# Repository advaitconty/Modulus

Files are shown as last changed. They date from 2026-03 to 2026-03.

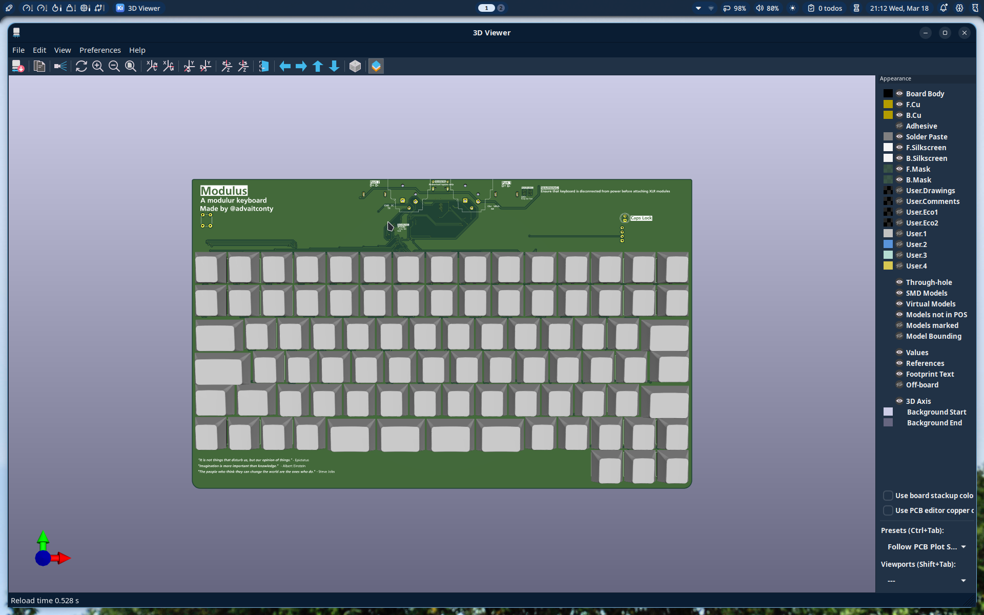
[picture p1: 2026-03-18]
Readme Images/Screenshot from 2026-03-18 21-12-29.png

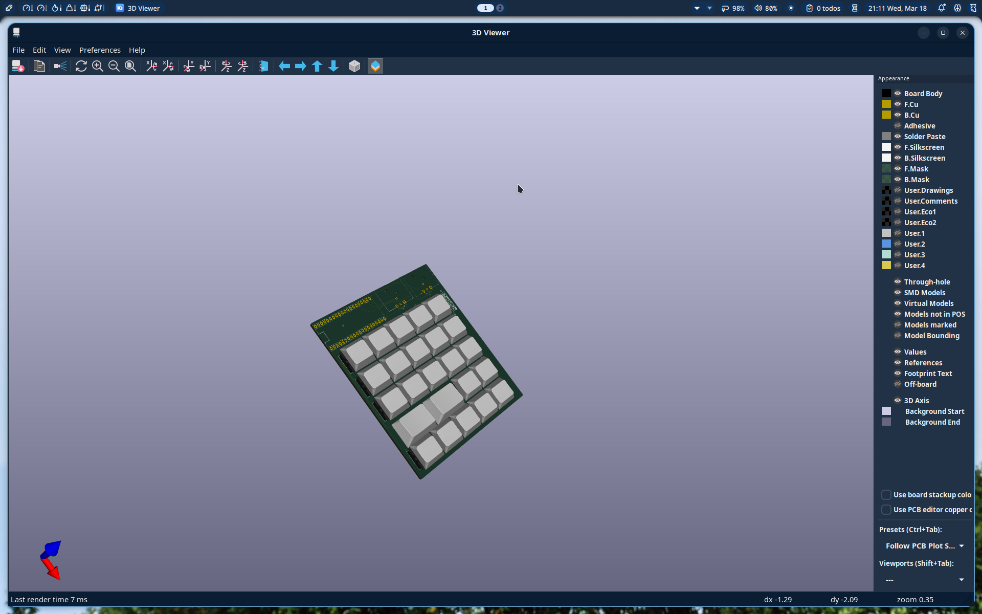
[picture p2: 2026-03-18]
Readme Images/Screenshot from 2026-03-18 21-11-40.png

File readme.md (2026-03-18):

# Modulus

A keyboard, built with the idea of expansion in the future, through SPI.

Things I will do later in the future (with other Hack Club events, or with my own money):
- Numpad over SPI
- Macropad over SPI

Just use it like a keyboard! However, any SPI accessories should be connected while the keyboard is powered down. This is mainly a limitation of SPI, as it is not hot-plug compatible.
The USB ports are USB 2.0 only, so it's better to be used for stuff like USB sound cards and mice.
I don't actually know how much lag will the ports create, because they're bottom mounted, in direct contact with foam, and is air cooled. So it may overheat (tried to add thermal dissiptation vias but effectiveness not tested)

Quirks:
- Case has holes at the bottom for cooling (yes I'm serious)

## Images

- model + board

- board only

(https://imgcdn.dev/i/YvtLNg)
(https://imgcdn.dev/i/YvtbGv)
(https://imgcdn.dev/i/YvteeN)
(https://imgcdn.dev/i/YvtqMq)
(https://imgcdn.dev/i/Yv8obV)
(https://imgcdn.dev/i/Yv8JGh)
(https://imgcdn.dev/i/YvJDMK)
(https://imgcdn.dev/i/YvJYlo)

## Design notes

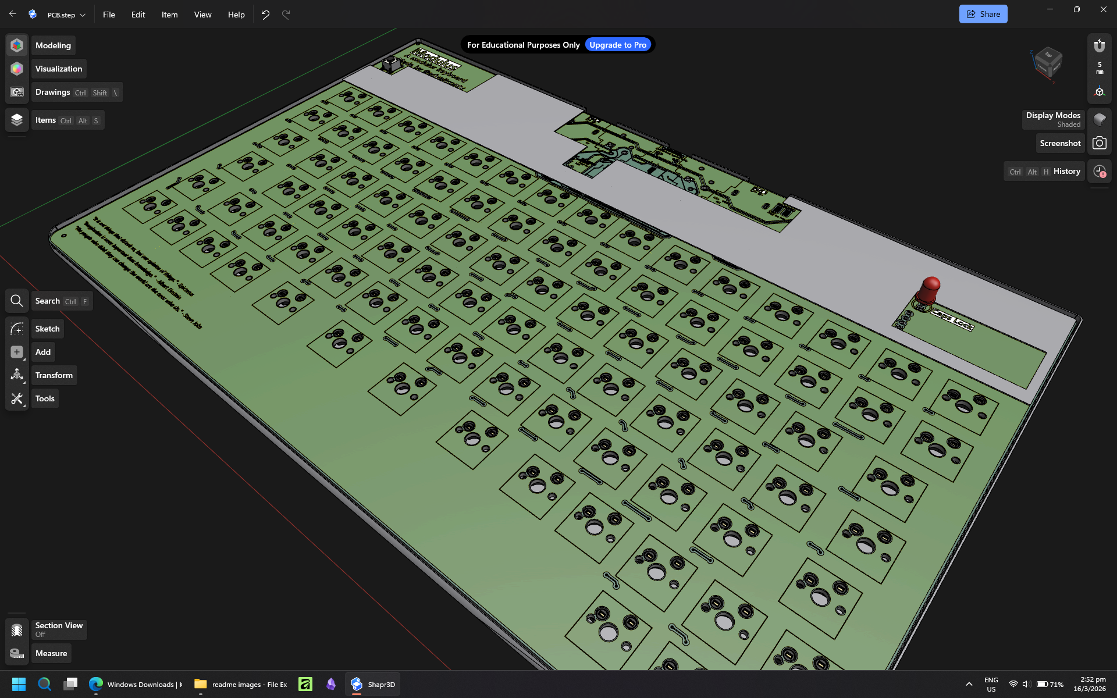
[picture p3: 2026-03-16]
Readme Images/Screenshot 2026-03-16 145249.png

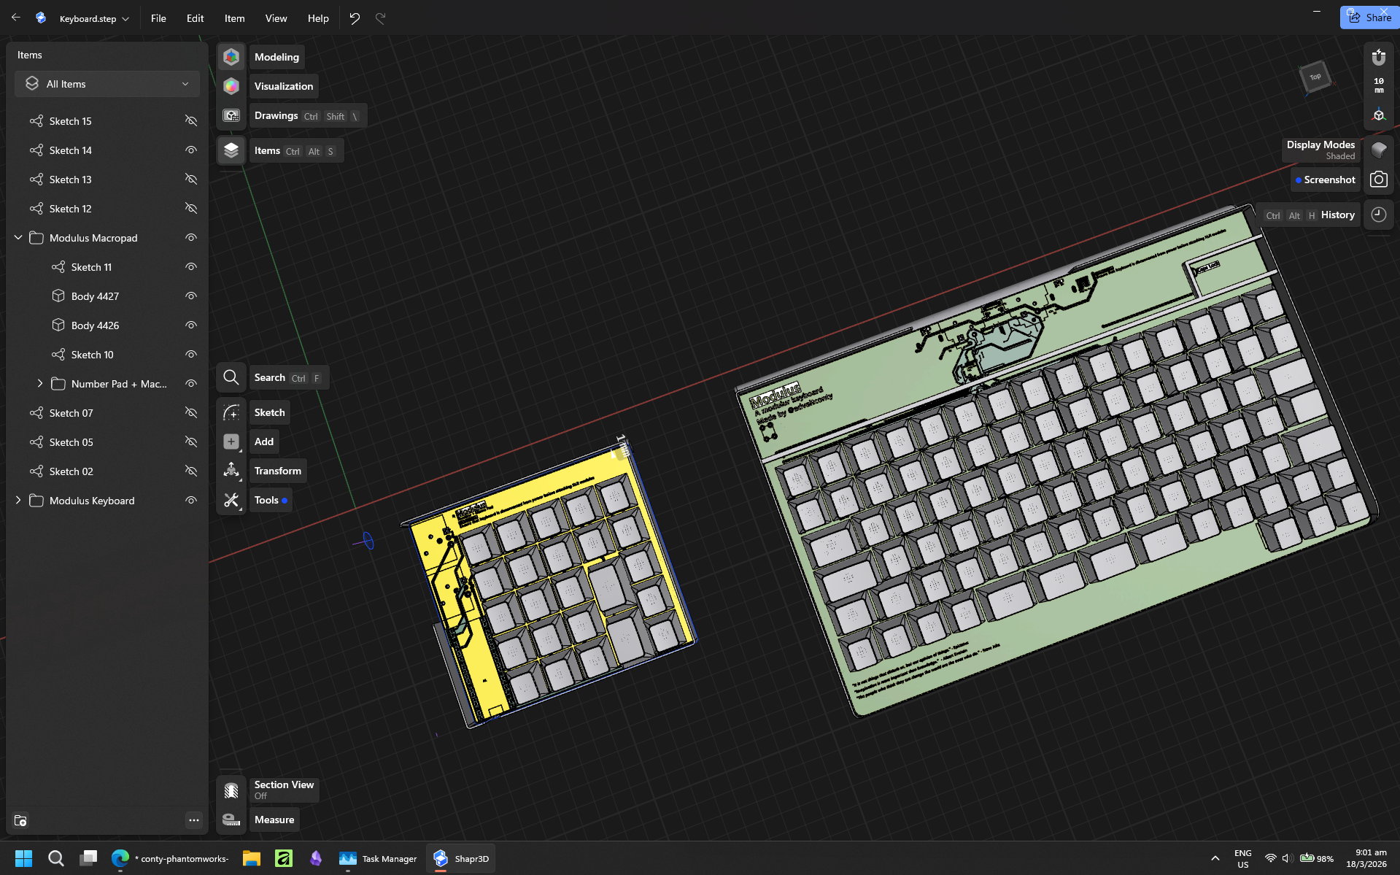
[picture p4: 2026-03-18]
Readme Images/With Macropad model.png

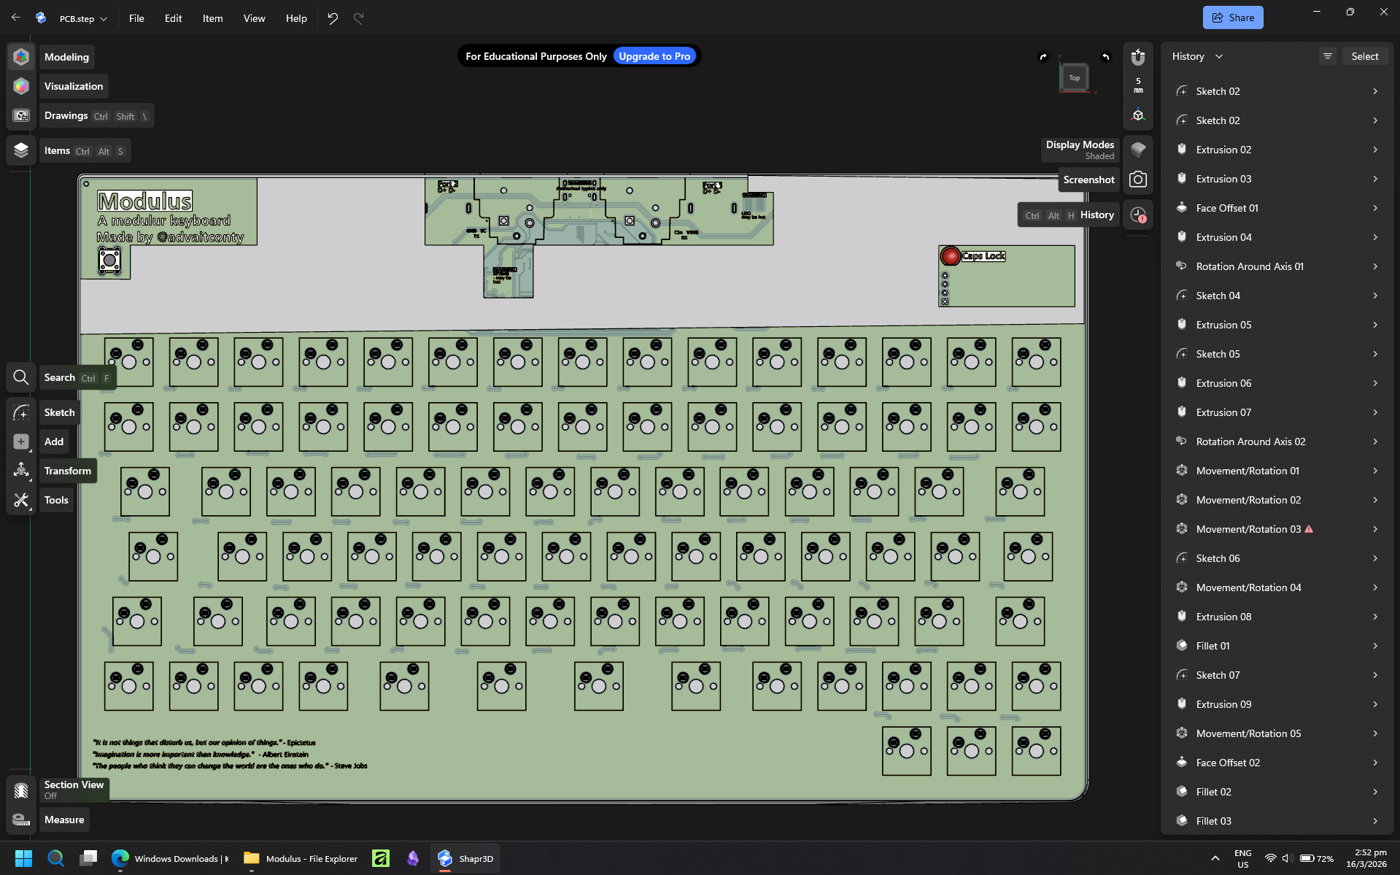
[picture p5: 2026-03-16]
Readme Images/Screenshot 2026-03-16 145220.png

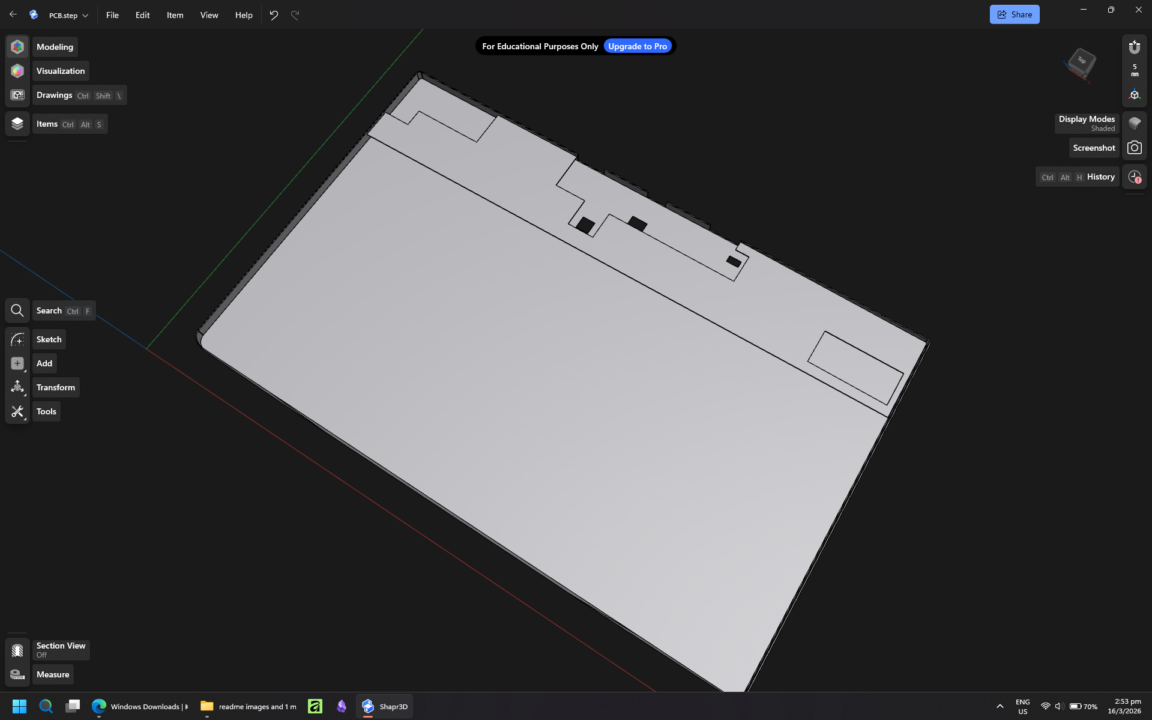
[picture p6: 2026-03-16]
Readme Images/Screenshot 2026-03-16 145345.png

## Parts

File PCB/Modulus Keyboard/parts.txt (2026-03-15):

I/O
Type C Receptable - https://jlcpcb.com/partdetail/Korean_HropartsElec-TYPE_C_31_M12/C165948
2x XLR - NC3FAAH - https://jlcpcb.com/partdetail/HOOYA-XLR_328P1/C309328
2x USB - https://jlcpcb.com/partdetail/7254738-USB1046_GF_0190_L_BA/C6307429

Chips
GL850G-HHY20 - https://jlcpcb.com/partdetail/GenesysLogic-GL850GHHY22/C136617
RP2040 - https://jlcpcb.com/partdetail/RaspberryPi-RP2040/C2040
Crystal - https://jlcpcb.com/partdetail/YXC_CrystalOscillators-X322512MSB4SI/C9002

Resistors
220ohm (0805) - https://jlcpcb.com/partdetail/18245-0805W8F2200T5E/C17557

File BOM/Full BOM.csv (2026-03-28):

Model | Item | Purpose | Vendor | Link | Qty | Unit Price | Total Price | Remarks
Neutrik NC3FAAH | XLR Connector (Female) | SPI over XLR connections on keyboard | LCSC | https://www.lcsc.com/product-detail/C368521.html | 2 | $1.59 | $3.18
Neutrik NC3MAH | XLR Connector (Male) | SPI over XLR connections on macropad | LCSC | https://www.lcsc.com/product-detail/C5154126.html | 2 | $1.98 | $3.96
BZCN TSD001A05518A | Button 6mmX6mm | Reset button | LCSC | https://www.lcsc.com/product-detail/C2889004.html | 50 | $0.01 | $0.50 | Purchase 50 due to minimum purchase quantity
UGREEN 60121 | USB-A to USB-C Cable (1m) | Keyboard connection | LCSC | https://www.lcsc.com/product-detail/C5189133.html | 1 | $2.54 | $2.54
Han Electricity CPG151101S11-16 | Hotswap Keyswitch | For keyboard | LCSC | https://www.lcsc.com/product-detail/C41430893.html | 120 | $0.03 | $4.12
Global Direct Standard Line | Shipping | Shipping | LCSC | - | 1 | $5.50 | $5.50
Keyboard | PCB | PCB | JLC | - | 5 | $28.00 | $28.00
Keyboard | PCB Assembly | Setup Fee | JLC | - | 1 | $8.12 | $8.12
Keyboard | PCB Assembly | Stencil | JLC | - | 1 | $1.52 | $1.52
Keyboard | PCB Assembly | Components | JLC | - | 1 | $14.94 | $14.94
Keyboard | PCB Assembly | Extended Components Fee | JLC | - | 1 | $18.24 | $18.24
Keyboard | PCB Assembly | SMT Assembly | JLC | - | 1 | $1.39 | $1.39
Keyboard | PCB Assembly | Nitrogen Reflow Soldering | JLC | - | 1 | $0.85 | $0.85
Macropad | PCB | PCB | JLC | - | 5 | $11.00 | $11.00
Macropad | PCB Assembly | Setup Fee | JLC | - | 1 | $8.12 | $8.12
Macropad | PCB Assembly | Stencil | JLC | - | 1 | $1.52 | $1.52
Macropad | PCB Assembly | Components | JLC | - | 1 | $0.55 | $0.55
Macropad | PCB Assembly | SMT Assembly | JLC | - | 1 | $0.16 | $0.16
Macropad | PCB Assembly | Nitrogen Reflow Soldering | JLC | - | 1 | $0.85 | $0.85
Shipping | Macropad + Keyboard Shipping | UPS Worldwide Saver | JLC | - | 1 | $19.71 | $19.71
KBDiy 147/Keys Modern-Dolch Keycaps | Keycaps for Keyboard | Keycaps | AliExpress | https://www.aliexpress.com/item/1005010169995953.html?mp=1 | 1 | $19.70 | $19.70
Samzhe XLR Cable | XLR Cables | For connecting macropad and keyboard | AliExpress | https://www.aliexpress.com/item/1005005725048225.html?mp=1 | 2 | $6.43 | $12.86
Outemu Silent Lemon V3s 110 switch pack | Keyswitch | Very nice keyswitch | AliExpress | https://www.aliexpress.com/item/1005005609580877.html?mp=1 | 1 | $21.03 | $21.03
128x32 OLED | Screen | Indicator on Keyboard | AliExpress | https://www.aliexpress.com/item/1005005301005280.html?mp=1 | 1 | $2.79 | $2.79 | I burnt the last one i soldered so i shall be smart and get one pre soldered-
Soldering Iron Tip | Chisel | For my tipless pinecil | AliExpress | https://www.aliexpress.com/item/1005006125240838.html?curPageLogUid=HrnIASZUeSxM | 1 | $5.03 | $5.03 | I was told this was allowed (https://hackclub.slack.com/archives/C09CMJV6V6K/p1774712666820039?thread_ts=1774710807.451839&cid=C09CMJV6V6K)
 |  |  |  |  |  | Total: | $196.18

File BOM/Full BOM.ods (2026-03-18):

Model | Item | Purpose | Vendor | Link | Qty | Unit Price | Total Price | Remarks
Neutrik NC3FAAH | XLR Connector (Female) | SPI over XLR connections on keyboard | LCSC | https://www.lcsc.com/product-detail/C368521.html | 2 | $1.59 | $3.17
Neutrik NC3MAH | XLR Connector (Male) | SPI over XLR connections on macropad | LCSC | https://www.lcsc.com/product-detail/C5154126.html | 2 | $1.98 | $3.96
BZCN TSD001A05518A | Button 6mmX6mm | Reset button | LCSC | https://www.lcsc.com/product-detail/C2889004.html | 50 | $0.01 | $0.53 | Purchase 50 due to minimum purchase quantity
UGREEN 60121 | USB-A to USB-C Cable (1m) | Keyboard connection | LCSC | https://www.lcsc.com/product-detail/C5189133.html | 1 | $2.54 | $2.54
Global Direct Standard Line | Shipping | Shipping | LCSC | - | 1 | $5.41 | $5.41
Modulus | Macropad | PCB | JLCPCB | - | 5 | - | $11.00
Modulus | Macropad PCBA | Assembly | JLCPCB | - | 2 | - | $16.39 | Refer to BOM for macropad (in same folder) for parts used
Modulus | Keyboard | PCB | JLCPCB | - | 5 | - | $25.70
Modulus | Keyboard PCBA | Assembly | JLCPCB | - | 2 | - | $55.43 | Refer to BOM for keyboard (in same folder) for parts used
UPS Worldwide Express Saver | Shipping | PCB shipping | JLCPCB | - | 1 | $18.67 | $18.67
KBDiy 147/Keys Modern-Dolch Keycaps | Keycaps for Keyboard | Keycaps | AliExpress |  | 1 | S$23.10 | S$23.10
Samzhe XLR Cable | XLR Cables | For connecting macropad and keyboard | AliExpress |  | 2 | S$7.09 | S$14.18
Outemu Silent Lemon V3s 110 switch pack | Keyswitch | Very nice keyswitch | AliExpress |  | 1 | S$29.17 | S$29.17
128x32 OLED | Screen | Indicator on Keyboard | AliExpress |  | 1 | S$3.47 | S$3.47 | I burnt the last one i soldered so i shall be smart and get one pre soldered-
 |  |  |  |  |  | TOTAL: | $197.40 | (usd)

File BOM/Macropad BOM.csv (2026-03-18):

Comment | Designator | Footprint | JLCPCB Part #
~ | S18,S1,S10,S11,S12,S13,S14,S15,S16,S17,S2,S20,S21,S22,S23,S24,S3,S4,S5,S6,S7,S8,S9,S18,S1,S10,S11,S12,S13,S14,S15,S16,S17,S2,S20,S21,S22,S23,S24,S3,S4,S5,S6,S7,S8,S9 | SW_Hotswap_Kailh_MX_1.00u | C41430893
Diode | D25,D1,D10,D11,D12,D13,D14,D15,D16,D17,D18,D19,D2,D20,D21,D22,D23,D24,D3,D4,D5,D6,D7,D8,D9,D25,D1,D10,D11,D12,D13,D14,D15,D16,D17,D18,D19,D2,D20,D21,D22,D23,D24,D3,D4,D5,D6,D7,D8,D9 | D_SMA | C81598

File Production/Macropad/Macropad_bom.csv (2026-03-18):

Designator | Footprint | Quantity | Value | LCSC Part #
A1 | raspberry_pi_pico_THT | 1 | Raspberry_Pi_Pico_THT
D1, D10, D11, D12, D13, D14, D15, D16, D17, D18, D19, D2, D20, D21, D22, D23, D24, D3, D4, D5, D6, D7, D8, D9 | D_SMA | 24 | Diode | C81598
D25 | D_SMA | 1 | D_Generic
J10, J9 | NEUTRIK_NC3MAH | 2 | NC3MAH
S1, S10, S11, S12, S13, S14, S15, S16, S17, S2, S20, S21, S22, S23, S24, S3, S4, S5, S6, S7, S8, S9 | SW_Hotswap_Kailh_MX_1.00u | 22 | ~ | C41430893
S18 | SW_Hotswap_Kailh_MX_1.50u_90deg | 1 | ~ | C41430893
S19 | SW_Hotswap_Kailh_MX_1.50u_90deg | 1 | ~

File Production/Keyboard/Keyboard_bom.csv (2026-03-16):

Designator | Footprint | Quantity | Value | LCSC Part #
-_1, 0)1, 1!1, 2@1, 3#1, 4$1, 5%1, 6^1, 7&1, 8*1, 9(1, =+1, BACKSPACE1, BACKSPACE2, COMMAND1, COMMAND2, CONTROL1, DEL1, DEL2, DOWN1, E1, ESC1, F1, F10, F11, F12, F2, F3, F4, F5, F6, F7, F8, F9, FN1, I1, LEFT1, O1, OPTION1, OPTION2, P1, PGDOWN1, PGUP1, Q1, RIGHT1, RKEY1, S46, S47, S48, S49, S50, S51, S52, S53, S54, S55, S56, S57, S61, S62, S63, S64, S65, S66, S67, S68, S69, S70, S71, T1, UKEY1, UP1, W1, YKEY11, [{1, ]}1, `~1 | SW_Hotswap_Kailh_MX_1.00u | 77 | Keyswitch | C41430893
-_D1, 0)D1, 1!D1, 2@D1, 3#D1, 4$D1, 5%D1, 6^D1, 7&D1, 8*D1, 9(D1, =+D1, BACKSPACED1, BACKSPACED2, D31, D32, D33, D34, D35, D36, D37, D38, D39, D40, D41, D42, D43, D44, D45, D46, D47, D48, D49, D50, D51, D52, D53, D54, D55, D56, D57, D58, D59, D60, D61, D62, D63, D64, D65, D66, D67, D68, D69, D70, D71, D72, D73, D74, D75, D76, D77, D78, D79, D80, D81, D82, D84, D85, D86, D87, D88, D89, DELD1, DELD2, ESCD1, F10D1, F11D1, F12D1, F1D1, F2D1, F3D1, F4D1, F5D1, F6D1, F7D1, F8D1, F9D1, `~D1 | D_SMA | 88 | Diode | C81598
C1, C10 | 1206 | 2 | 1uF | C1848
C11, C12, C17, C2, C3, C4, C5, C6, C7, C8, C9 | 1206 | 11 | 0.1uF | C24497
C13, C14 | 1206 | 2 | 10uF | C13585
C15, C16, C20, C21 | 0805 | 4 | 33pF | C107115
C22, C23, C24, C25, C26, C27 | 1206 | 6 | 100nF | C1848
D91 | LED_D5.0mm | 1 | LED
GL850G1 | 28SSOP | 1 | GL850G | C7501406
J1, J5 | NEUTRIK_NC3FAAH | 2 | XLR3 | C368521
J2 | USB_C_HRO_TYPE-C-31-M-12 | 1 | USB_C_Receptacle_USB2.0_16P | C165948
J3, J4 | GCT_USB1046-GF-0190-L-B-A_REVB4 | 2 | USB_A | C6307429
J6 | OLED_128x32 | 1 | OLED_128x32
R1 | 0805 | 1 | 680 | C17798
R11 | 0402 | 1 | 88.7K | C25922
R12, R15, R16, R17, R7 | 1206 | 5 | 10K | C17902
R13, R8, R9 | 0805 | 3 | 5.1K | C27834
R14, R5, R6 | 1206 | 3 | 1K | C4410
R3, R4 | 0805 | 2 | 27 | C17594
S45 | SW_Hotswap_Kailh_MX_1.75u | 1 | Keyswitch | C41430893
S58, S59, S60 | SW_Hotswap_Kailh_MX_1.25u | 3 | Keyswitch | C41430893
S72, SPACE1, SPACE2, SPACE3, SPACE4, TAB1, \|1 | SW_Hotswap_Kailh_MX_1.50u | 7 | Keyswitch | C41430893
SW1 | SW_PUSH_6mm | 1 | Push_Button
U1 | QFN-56-1EP_7x7mm_P0.4mm_EP3.2x3.2mm | 1 | RP2040 | C2040
U3 | SOIC-8_5.3x5.3mm_P1.27mm | 1 | W25Q128JVS | C97521
U4 | SOT-223-3_TabPin2 | 1 | NCP1117-3.3_SOT223 | C26537
Y1, Y2 | Crystal_SMD_3225-4Pin_3.2x2.5mm | 2 | 12MHz | C9002

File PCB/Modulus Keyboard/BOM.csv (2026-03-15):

Reference | Qty | Value | Footprint | MF | MP | Package | Total Price | JLCPCB Part # | Extended Parts | Purchasing Seperately
-_1,0)1,1!1,2@1,3#1,4$1,5%1,6^1,7&1,8*1,9(1,=+1,Backspace1,Backspace2,Command1,Command2,Control1,Del1,Del2,Down1,E1,Esc1,F1,F2,F3,F4,F5,F6,F7,F8,F9,F10,F11,F12,Fn1,I1,Left1,O1,Option1,Option2,P1,PgDown1,PgUp1,Q1,Right1,RKey1,S46,S47,S48,S49,S50,S51,S52,S53,S54,S55,S56,S57,S61,S62,S63,S64,S65,S66,S67,S68,S69,S70,S71,T1,UKey1,UP1,W1,YKey11,[{1,]}1,`~1 | 88 | Keyswitch | ScottoKeebs_Hotswap:Hotswap_MX_1.00u | HanElectricity | CPG151101S11-16 | SMD,14.5x5.9mm | 3.82 | C41430893 | TRUE | FALSE
-_D1,0)D1,1!D1,2@D1,3#D1,4$D1,5%D1,6^D1,7&D1,8*D1,9(D1,=+D1,BackspaceD1,BackspaceD2,D31,D32,D33,D34,D35,D36,D37,D38,D39,D40,D41,D42,D43,D44,D45,D46,D47,D48,D49,D50,D51,D52,D53,D54,D55,D56,D57,D58,D59,D60,D61,D62,D63,D64,D65,D66,D67,D68,D69,D70,D71,D72,D73,D74,D75,D76,D77,D78,D79,D80,D81,D82,D84,D85,D86,D87,D88,D89,DelD1,DelD2,EscD1,F1D1,F2D1,F3D1,F4D1,F5D1,F6D1,F7D1,F8D1,F9D1,F10D1,F11D1,F12D1,`~D1 | 88 | Diode | Diode_SMD:D_SMA | ST(Semtech) | 1N4148W | SOD-123 | 0.97 | C81598 | FALSE | FALSE
C1,C10 | 2 | 1uF | Capacitor_SMD:C_1206_3216Metric | Samsung Electro-Mechanics | CL31B105KBHNNNE | 1206 | 0.06 | C1848 | FALSE | FALSE
C2,C3,C4,C5,C6,C7,C8,C9,C11,C12,C17 | 11 | 0.1uF | Capacitor_SMD:C_1206_3216Metric | Samsung Electro-Mechanics | CL31B104KBCNNNC | 1206 | 0.17 | C24497 | FALSE | FALSE
C13,C14 | 2 | 10uF | Capacitor_SMD:C_1206_3216Metric | Samsung Electro-Mechanics | CL31A106KBHNNNE | 1206 | 0.12 | C13585 | FALSE | FALSE
C15,C16,C20,C21 | 4 | 33pF | Capacitor_SMD:C_0805_2012Metric | YAGEO | CC0805JRNPO9BN330 | 0805 | 0.02 | C107115 | FALSE | FALSE
C22,C23,C24,C25,C26,C27 | 6 | 100nF | Capacitor_SMD:C_1206_3216Metric | Samsung Electro-Mechanics | CL31B105KBHNNNE | 1206 | 0.06 | C1848 | FALSE | FALSE
D91 | 1 | LED | Green_LED:0603 | Hubei KENTO Elec | KT-0603W | 0603 | 0.01 | C2290 | FALSE | FALSE
GL850G1 | 1 | GL850G | GL850G:28SSOP | Genesys Logic | GL850G-HHY60 | SSOP-28 | 0.68 | C7501406 | TRUE | FALSE
J1,J5 | 2 | XLR3 | NC3FAAH:NEUTRIK_NC3FAAH | Neutrik | NC3FAAH | Plugin | 3.13 | C368521 | TRUE | TRUE
J2 | 1 | USB_C_Receptacle_USB2.0_16P | ScottoKeebs_Components:USB_C_HRO_TYPE-C-31-M-12 | Korean Hroparts Elec | TYPE-C-31-M-12 | SMD | 0.18 | C165948 | TRUE | FALSE
J3,J4 | 2 | USB_A | USB1046-GF-0190-L-B-A_REVB4:GCT_USB1046-GF-0190-L-B-A_REVB4 | Global Connector Technology | USB1046-GF-0190-L-B-A | SMD | 1.53 | C6307429 | TRUE | FALSE
J6 | 1 | OLED_128x32 | ScottoKeebs_Components:OLED_128x32 |  |  |  |  |  | FALSE | TRUE
R1 | 1 | 680 | Resistor_SMD:R_0805_2012Metric | UNI-ROYAL(Uniroyal Elec) | 0805W8F6800T5E | 0805 | 0.00 | C17798 | FALSE | FALSE
R3,R4 | 2 | 27 | Resistor_SMD:R_0805_2012Metric | UNI-ROYAL(Uniroyal Elec) | 0805W8F270JT5E | 0805 | 0.00 | C17594 | FALSE | FALSE
R5,R6,R14 | 3 | 1K | Resistor_SMD:R_1206_3216Metric | UNI-ROYAL(Uniroyal Elec) | 1206W4F1001T5E | 1206 | 0.01 | C4410 | FALSE | FALSE
R7,R12,R15 | 3 | 10K | Resistor_SMD:R_1206_3216Metric | UNI-ROYAL(Uniroyal Elec) | 1206W4F1002T5E | 1206 | 0.01 | C17902 | FALSE | FALSE
R8,R9,R13 | 3 | 5.1K | Resistor_SMD:R_0805_2012Metric | UNI-ROYAL(Uniroyal Elec) | 0805W8F5101T5E | 0805 | 0.01 | C27834 | FALSE | FALSE
R11 | 1 | 88.7K | Resistor_SMD:R_0402_1005Metric | UNI-ROYAL(Uniroyal Elec) | 0402WGF8872TCE | 0402 | 0.00 | C25922 | TRUE | FALSE
 |  |  |  |  |  |  |  |  | FALSE | FALSE
R16,R17 | 2 | 10k | Resistor_SMD:R_1206_3216Metric | UNI-ROYAL(Uniroyal Elec) | 1206W4F1002T5E | 1206 | 0.01 | C17902 | FALSE | FALSE
 |  |  |  |  |  |  |  |  | FALSE | FALSE
 |  |  |  |  |  |  |  |  | FALSE | FALSE
 |  |  |  |  |  |  |  |  | FALSE | FALSE
SW1 | 1 | Push_Button | Button_Switch_THT:SW_PUSH_6mm | BZCN | TSD007A05026A03 | 弯插,6x6mm | 0.01 | C2888566 | FALSE | TRUE
U1 | 1 | RP2040 | Package_DFN_QFN:QFN-56-1EP_7x7mm_P0.4mm_EP3.2x3.2mm | Raspberry Pi | RP2040 | LQFN-56(7x7) | 0.97 | C2040 | TRUE | FALSE
U4 | 1 | NCP1117-3.3_SOT223 | Package_TO_SOT_SMD:SOT-223-3_TabPin2 | onsemi | NCP1117ST33T3G | SOT-223 | 0.24 | C26537 | TRUE | FALSE
U3 | 1 | W25Q128JVS | Package_SO:SOIC-8_5.3x5.3mm_P1.27mm | Winbond Elec | W25Q128JVSIQ | SOIC-8-208mil | 2.33 | C97521 | FALSE | FALSE
Y1,Y2 | 2 | 12MHz | Crystal:Crystal_SMD_3225-4Pin_3.2x2.5mm | YXC Crystal Oscillators | X322512MSB4SI | SMD3225-4P | 0.15 | C9002 | FALSE | FALSE
 |  |  |  |  |  |  | 14.49 |  | FALSE | FALSE

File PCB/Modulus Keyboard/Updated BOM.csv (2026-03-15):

Id | Designator | Footprint | Quantity | Designation | Supplier and ref
1 | U4 | SOT-223-3_TabPin2 | 1 | NCP1117-3.3_SOT223
2 | Caps Lock | 0603 | 1 | LED
3 | R6,R14,R5 | R_1206_3216Metric | 3 | 1K
4 | R4,R3 | R_0805_2012Metric | 2 | 27
5 | C9,C7,C12,C17,C6,C11,C3,C4,C2,C5,C8 | C_1206_3216Metric | 11 | 0.1uF
6 | S47,F9,Command1,S51,S55,YKey11,PgUp1,S65,P1,S69,9(1,5%1,1!1,S56,Q1,0)1,F12,-_1,Backspace2,RKey1,S53,Command2,T1,S71,4$1,S68,S52,S54,F10,S63,Option1,]}1,S67,F8,S61,S50,Left1,S66,`~1,S62,S49,Backspace1,E1,F3,F11,Del1,I1,Control1,7&1,F2,Option2,8*1,Down1,2@1,F6,S48,F1,[{1,S70,UP1,Fn1,F5,Esc1,W1,O1,3#1,S64,6^1,Right1,Del2,PgDown1,F4,S46,F7,=+1,UKey1,S57 | Hotswap_MX_1.00u | 77 | Keyswitch
7 | S58,S59,S60 | Hotswap_MX_1.25u | 3 | Keyswitch
8 | GL850G1 | 28SSOP | 1 | GL850G
9 | R1 | R_0805_2012Metric | 1 | 680
10 | Y2,Y1 | Crystal_SMD_3225-4Pin_3.2x2.5mm | 2 | 12MHz
11 | C21,C16,C20,C15 | C_0805_2012Metric | 4 | 33pF
12 | R11 | R_0402_1005Metric | 1 | 88.7K
13 | C26,C27,C24,C23,C25,C22 | C_1206_3216Metric | 6 | 100nF
14 | C1,C10 | C_1206_3216Metric | 2 | 1uF
15 | J6 | OLED_128x32 | 1 | OLED_128x32
16 | U1 | QFN-56-1EP_7x7mm_P0.4mm_EP3.2x3.2mm | 1 | RP2040
17 | U3 | SOIC-8_5.3x5.3mm_P1.27mm | 1 | W25Q128JVS
18 | Space1,Tab1,Space3,Space2,Space4,S72,\|1 | Hotswap_MX_1.50u | 7 | Keyswitch
19 | R9,R13,R8 | R_0805_2012Metric | 3 | 5.1K
20 | R17,R16 | R_1206_3216Metric | 2 | 10k
21 | R7,R12,R15 | R_1206_3216Metric | 3 | 10K
22 | S45 | Hotswap_MX_1.75u | 1 | Keyswitch
23 | C14,C13 | C_1206_3216Metric | 2 | 10uF
24 | J3,J4 | GCT_USB1046-GF-0190-L-B-A_REVB4 | 2 | USB_A
25 | J1,J5 | NEUTRIK_NC3FAAH | 2 | XLR3
26 | J2 | USB_C_HRO_TYPE-C-31-M-12 | 1 | USB_C_Receptacle_USB2.0_16P
27 | D62,F3D1,F11D1,F9D1,D72,D71,D56,D40,D33,9(D1,F6D1,5%D1,D61,D43,D89,DelD1,D79,D37,D70,D42,D81,D77,D39,D78,D73,F10D1,D38,D55,D57,D69,D49,-_D1,D63,D74,DelD2,EscD1,D41,D86,F2D1,F1D1,D80,D45,`~D1,F7D1,D52,8*D1,D66,D65,D82,F8D1,D34,7&D1,4$D1,D54,D68,0)D1,D50,D58,D32,D88,D36,1!D1,D51,BackspaceD1,D35,D46,D67,F5D1,D44,D48,BackspaceD2,D75,D76,D59,F4D1,D47,D87,D31,2@D1,=+D1,D64,F12D1,D53,D85,6^D1,D84,3#D1,D60 | D_SMA | 88 | Diode

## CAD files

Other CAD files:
Case/Full Design.step
Case/Keyboard/Keyboard Only.step
Case/Macropad/Case Only.step
Case/PCBs/Keyboard.step
PCB/Modulus Keyboard/3d models for keycaps + keyswitches/keycaps/1.25u.step
PCB/Modulus Keyboard/3d models for keycaps + keyswitches/keyswitch.step
PCB/Modulus Keyboard/LTST-C193TGKT-5A/LTST-C193TGKT-5A.step
PCB/Modulus Keyboard/Modulus.step
PCB/Modulus Keyboard/NC3FAAH/NC3FAAH.step
PCB/Modulus Keyboard/Other Footprints/NC3MAH/NC3MAH.step
PCB/Modulus Keyboard/SS34/SS34.step
PCB/Modulus Keyboard/USB1046-GF-0190-L-B-A_REVB4/USB1046-GF-0190-L-B-A_REVB4.step
PCB/Modulus Macropad/3d models for keycaps + keyswitches/keycaps/1.75u.step
PCB/Modulus Macropad/3d models for keycaps + keyswitches/keyswitch.step
PCB/Modulus Macropad/Other Footprints/NC3MAH/NC3MAH.step
Case/Keyboard/Case Only.step
Case/Macropad/Macropad Only.step
Case/PCBs/Number Pad + Macropad.step
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

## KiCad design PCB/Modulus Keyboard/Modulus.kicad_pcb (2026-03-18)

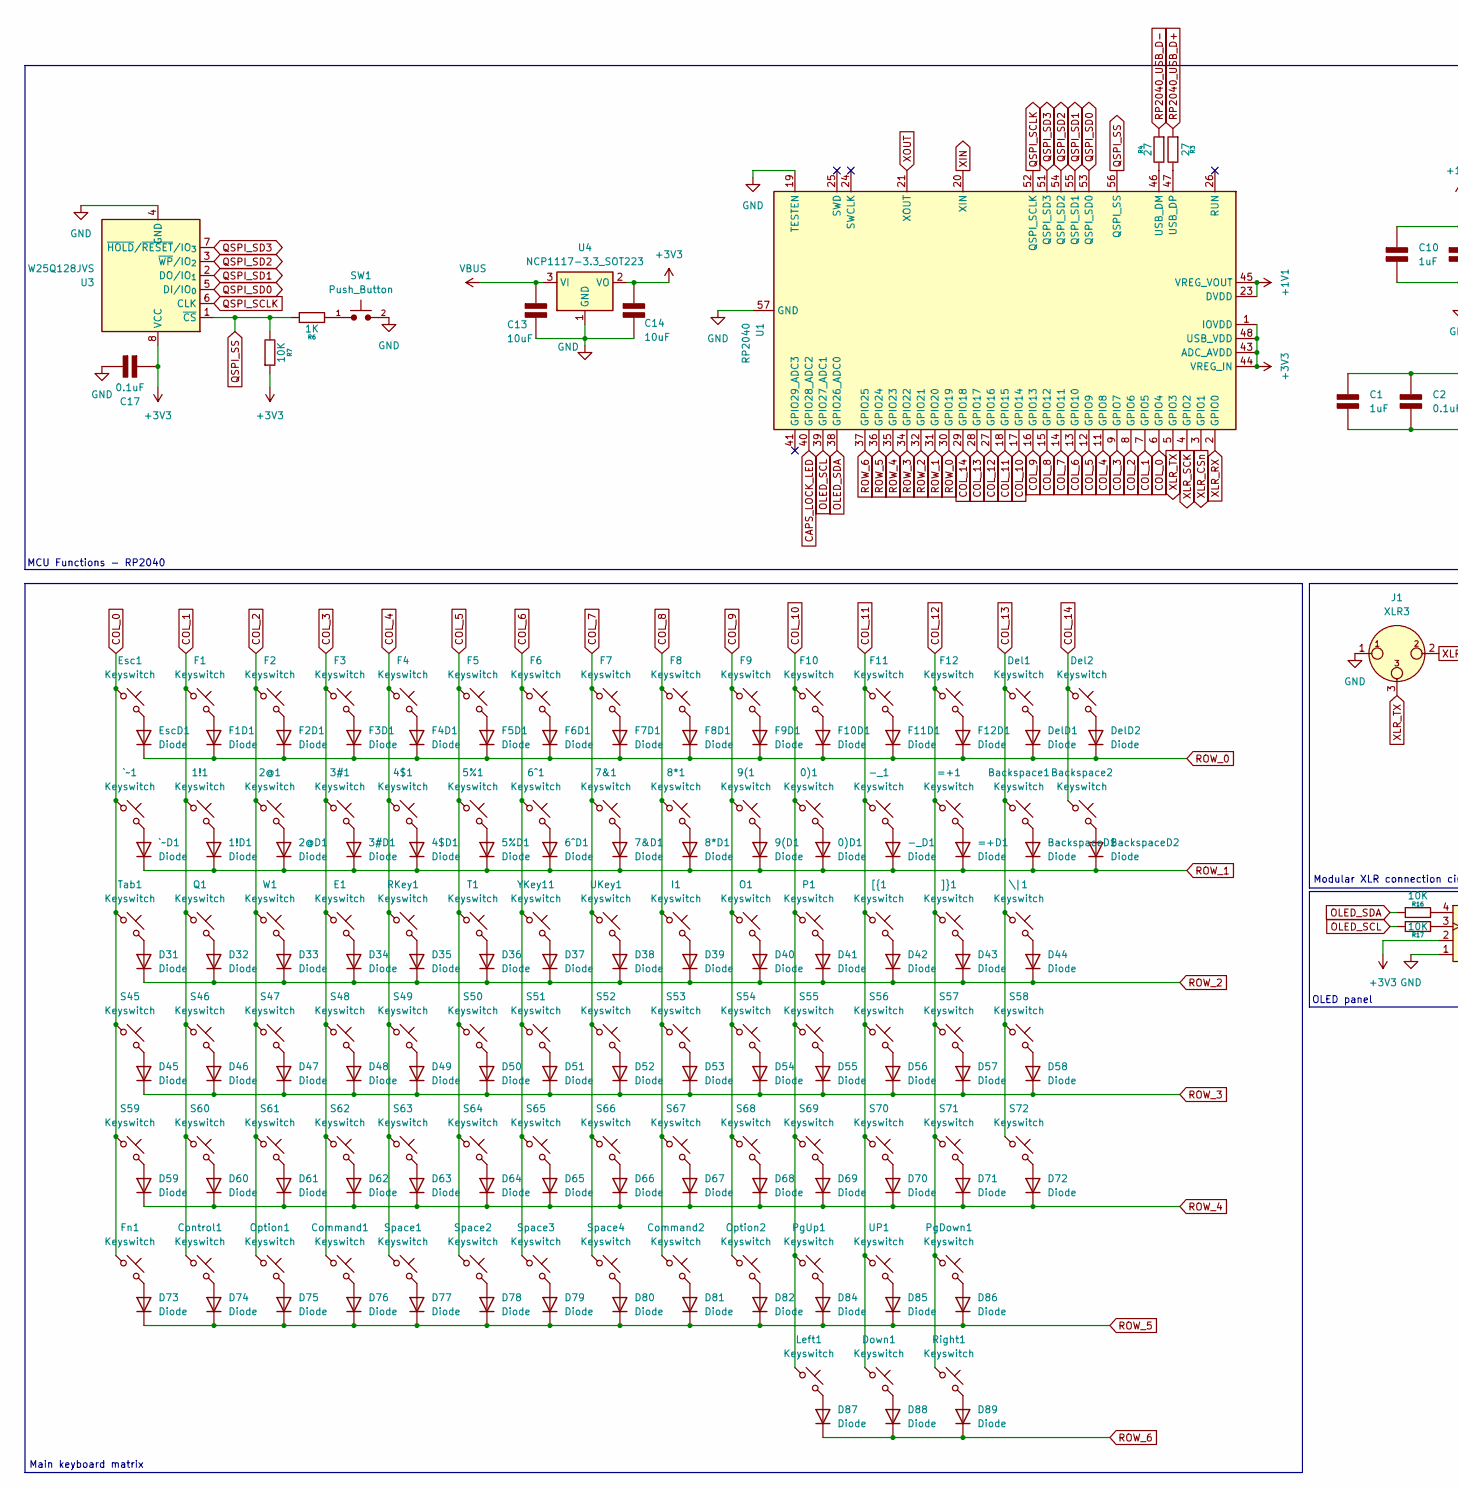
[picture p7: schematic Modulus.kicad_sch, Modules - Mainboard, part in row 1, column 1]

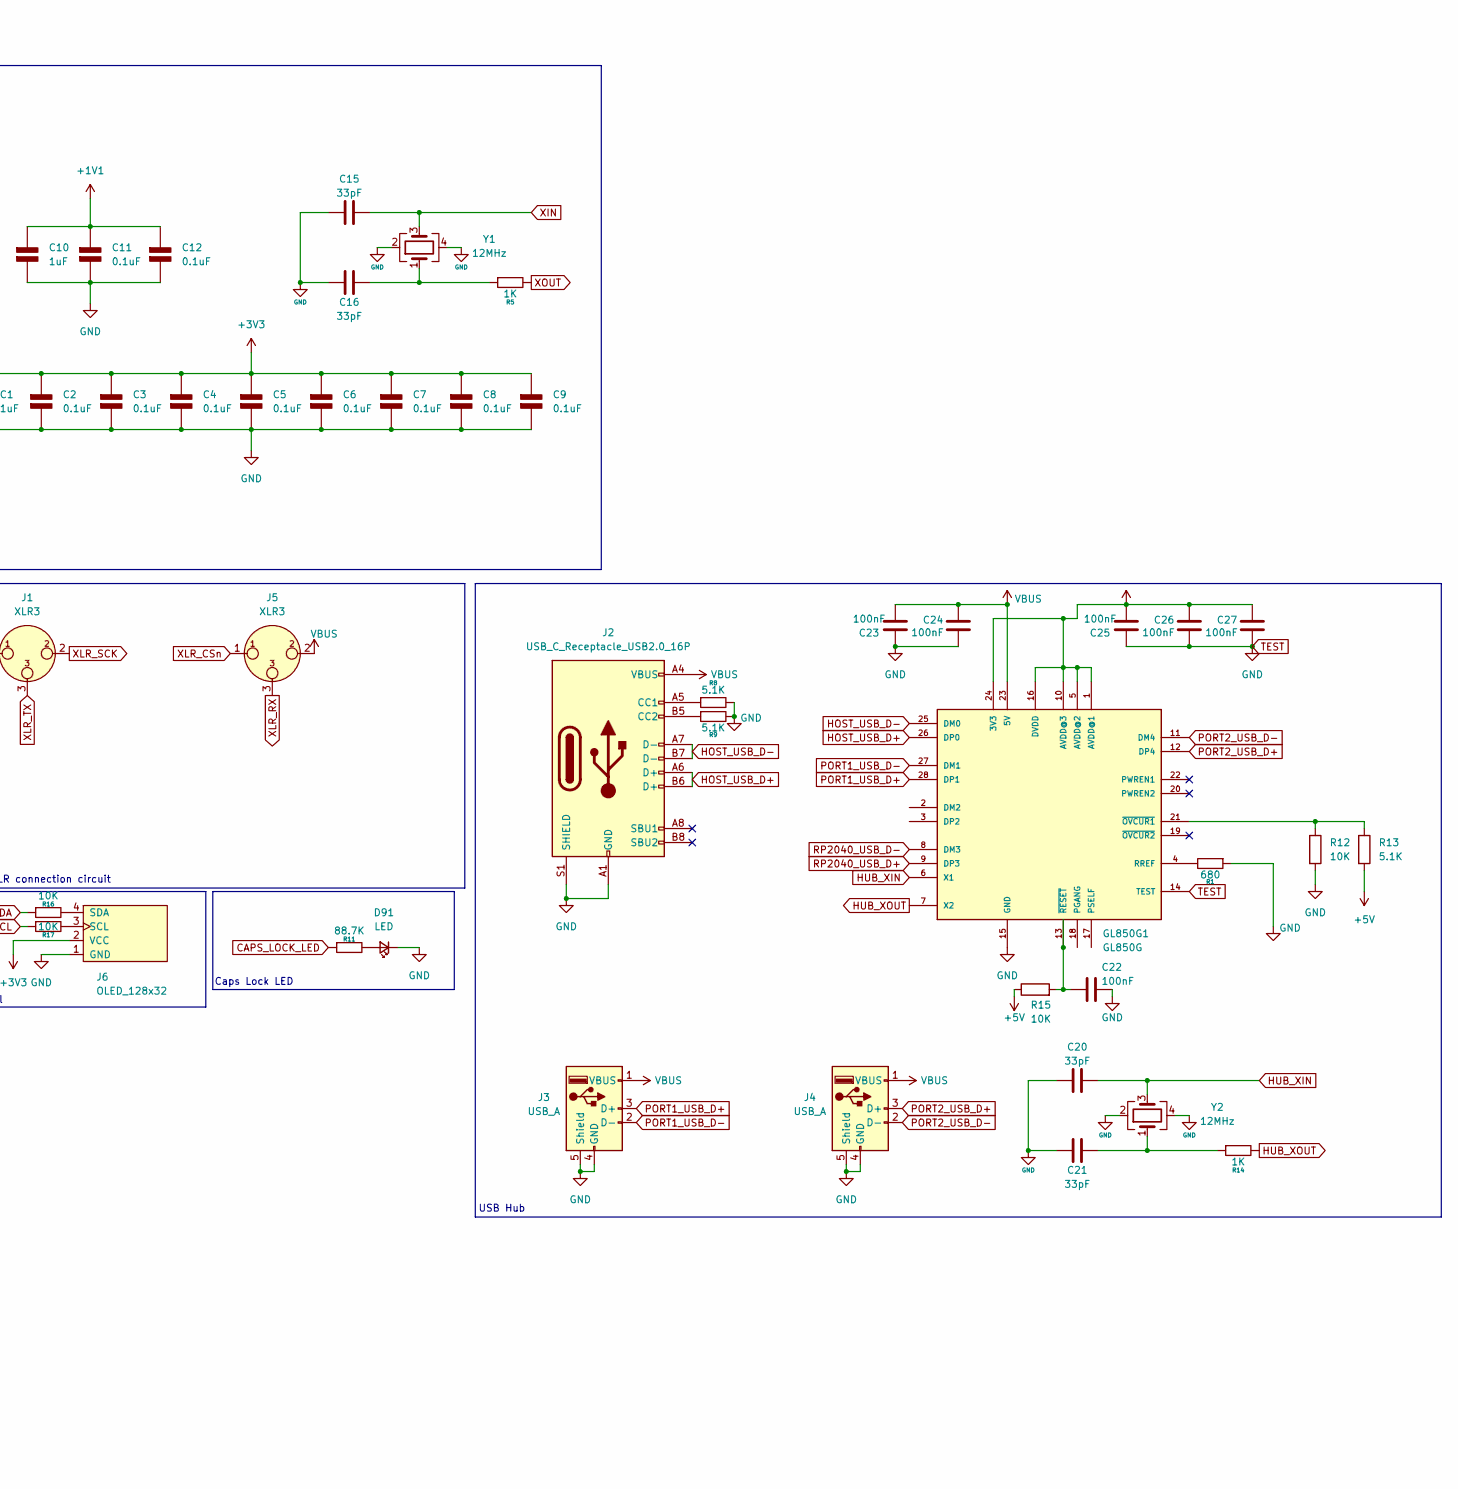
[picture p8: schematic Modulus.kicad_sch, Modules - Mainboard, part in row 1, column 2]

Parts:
0)1, 1!1, 2@1, 3#1, 4$1, 5%1, 6^1, 7&1, 8*1, 9(1: Keyswitch; SW_Hotswap_Kailh_MX_1.00u; JLCPCB Part # C41430893
0)D1, 1!D1, 2@D1, 3#D1, 4$D1, 5%D1, 6^D1, 7&D1, 8*D1, 9(D1: Diode; D_SMA; JLCPCB Part # C81598
-_1: Keyswitch; SW_Hotswap_Kailh_MX_1.00u; JLCPCB Part # C41430893
-_D1: Diode; D_SMA; JLCPCB Part # C81598
=+1: Keyswitch; SW_Hotswap_Kailh_MX_1.00u; JLCPCB Part # C41430893
=+D1: Diode; D_SMA; JLCPCB Part # C81598
Backspace1, Backspace2: Keyswitch; SW_Hotswap_Kailh_MX_1.00u; JLCPCB Part # C41430893
BackspaceD1, BackspaceD2: Diode; D_SMA; JLCPCB Part # C81598
C1, C10: 1uF; C_1206_3216Metric; Rating V; JLCPCB Part # C1848
C2, C3, C4, C5, C6, C7, C8, C9, C11, C12, C17: 0.1uF; C_1206_3216Metric; Rating V; JLCPCB Part # C24497
C13, C14: 10uF; C_1206_3216Metric; Rating V; JLCPCB Part # C13585
C15, C16, C20, C21: 33pF; C_0805_2012Metric; JLCPCB Part # C107115
C22, C23, C24, C25, C26, C27: 100nF; C_1206_3216Metric; JLCPCB Part # C1848
Command1, Command2: Keyswitch; SW_Hotswap_Kailh_MX_1.00u; JLCPCB Part # C41430893
Control1: Keyswitch; SW_Hotswap_Kailh_MX_1.00u; JLCPCB Part # C41430893
D31, D32, D33, D34, D35, D36, D37, D38, D39, D40, D41, D42, D43, D44, D45, D46, D47, D48, D49, D50, D51, D52, D53, D54, D55, D56, D57, D58, D59, D60, D61, D62, D63, D64, D65, D66, D67, D68, D69, D70, D71, D72, D73, D74, D75, D76, D77, D78, D79, D80, D81, D82, D84, D85, D86, D87, D88, D89: Diode; D_SMA; JLCPCB Part # C81598
D91: LED; LED_D5.0mm
Del1, Del2: Keyswitch; SW_Hotswap_Kailh_MX_1.00u; JLCPCB Part # C41430893
DelD1, DelD2: Diode; D_SMA; JLCPCB Part # C81598
Down1: Keyswitch; SW_Hotswap_Kailh_MX_1.00u; JLCPCB Part # C41430893
E1: Keyswitch; SW_Hotswap_Kailh_MX_1.00u; JLCPCB Part # C41430893
Esc1: Keyswitch; SW_Hotswap_Kailh_MX_1.00u; JLCPCB Part # C41430893
EscD1: Diode; D_SMA; JLCPCB Part # C81598
F1, F2, F3, F4, F5, F6, F7, F8, F9, F10, F11, F12: Keyswitch; SW_Hotswap_Kailh_MX_1.00u; JLCPCB Part # C41430893
F1D1, F2D1, F3D1, F4D1, F5D1, F6D1, F7D1, F8D1, F9D1, F10D1, F11D1, F12D1: Diode; D_SMA; JLCPCB Part # C81598
Fn1: Keyswitch; SW_Hotswap_Kailh_MX_1.00u; JLCPCB Part # C41430893
GL850G1: GL850G; 28SSOP; JLCPCB Part # C7501406
I1: Keyswitch; SW_Hotswap_Kailh_MX_1.00u; JLCPCB Part # C41430893
J1, J5: XLR3; NEUTRIK_NC3FAAH; JLCPCB Part # C368521
J2: USB_C_Receptacle_USB2.0_16P; USB_C_HRO_TYPE-C-31-M-12; JLCPCB Part # C165948
J3, J4: USB_A; GCT_USB1046-GF-0190-L-B-A_REVB4; JLCPCB Part # C6307429
J6: OLED_128x32
Left1: Keyswitch; SW_Hotswap_Kailh_MX_1.00u; JLCPCB Part # C41430893
O1: Keyswitch; SW_Hotswap_Kailh_MX_1.00u; JLCPCB Part # C41430893
Option1, Option2: Keyswitch; SW_Hotswap_Kailh_MX_1.00u; JLCPCB Part # C41430893
P1: Keyswitch; SW_Hotswap_Kailh_MX_1.00u; JLCPCB Part # C41430893
PgDown1: Keyswitch; SW_Hotswap_Kailh_MX_1.00u; JLCPCB Part # C41430893
PgUp1: Keyswitch; SW_Hotswap_Kailh_MX_1.00u; JLCPCB Part # C41430893
Q1: Keyswitch; SW_Hotswap_Kailh_MX_1.00u; JLCPCB Part # C41430893
R1: 680; R_0805_2012Metric; JLCPCB Part # C17798
R3, R4: 27; R_0805_2012Metric; JLCPCB Part # C17594
R5, R6, R14: 1K; R_1206_3216Metric; JLCPCB Part # C4410
R7, R12, R15, R16, R17: 10K; R_1206_3216Metric; JLCPCB Part # C17902
R8, R9, R13: 5.1K; R_0805_2012Metric; JLCPCB Part # C27834
R11: 88.7K; R_0402_1005Metric; JLCPCB Part # C25922
RKey1: Keyswitch; SW_Hotswap_Kailh_MX_1.00u; JLCPCB Part # C41430893
Right1: Keyswitch; SW_Hotswap_Kailh_MX_1.00u; JLCPCB Part # C41430893
S45: Keyswitch; SW_Hotswap_Kailh_MX_1.75u; JLCPCB Part # C41430893
S46, S47, S48, S49, S50, S51, S52, S53, S54, S55, S56, S57, S61, S62, S63, S64, S65, S66, S67, S68, S69, S70, S71: Keyswitch; SW_Hotswap_Kailh_MX_1.00u; JLCPCB Part # C41430893
S58, S59, S60: Keyswitch; SW_Hotswap_Kailh_MX_1.25u; JLCPCB Part # C41430893
S72: Keyswitch; SW_Hotswap_Kailh_MX_1.50u; JLCPCB Part # C41430893
SW1: Push_Button; SW_PUSH_6mm
Space1, Space2, Space3, Space4: Keyswitch; SW_Hotswap_Kailh_MX_1.50u; JLCPCB Part # C41430893
T1: Keyswitch; SW_Hotswap_Kailh_MX_1.00u; JLCPCB Part # C41430893
Tab1: Keyswitch; SW_Hotswap_Kailh_MX_1.50u; JLCPCB Part # C41430893
U1: RP2040; QFN-56-1EP_7x7mm_P0.4mm_EP3.2x3.2mm; JLCPCB Part # C2040
U3: W25Q128JVS; SOIC-8_5.3x5.3mm_P1.27mm; JLCPCB Part # C97521
U4: NCP1117-3.3_SOT223; SOT-223-3_TabPin2; JLCPCB Part # C26537
UKey1: Keyswitch; SW_Hotswap_Kailh_MX_1.00u; JLCPCB Part # C41430893
UP1: Keyswitch; SW_Hotswap_Kailh_MX_1.00u; JLCPCB Part # C41430893
W1: Keyswitch; SW_Hotswap_Kailh_MX_1.00u; JLCPCB Part # C41430893
Y1, Y2: 12MHz; Crystal_SMD_3225-4Pin_3.2x2.5mm; JLCPCB Part # C9002
YKey11: Keyswitch; SW_Hotswap_Kailh_MX_1.00u; JLCPCB Part # C41430893
[{1: Keyswitch; SW_Hotswap_Kailh_MX_1.00u; JLCPCB Part # C41430893
\|1: Keyswitch; SW_Hotswap_Kailh_MX_1.50u; JLCPCB Part # C41430893
]}1: Keyswitch; SW_Hotswap_Kailh_MX_1.00u; JLCPCB Part # C41430893
`~1: Keyswitch; SW_Hotswap_Kailh_MX_1.00u; JLCPCB Part # C41430893
`~D1: Diode; D_SMA; JLCPCB Part # C81598

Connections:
+1V1: C10.1 (+), C11.1 (+), C12.1 (+), U1.23 (DVDD), U1.45 (VREG_VOUT), U1.50 (DVDD)
+3V3: C1.1 (+), C2.1 (+), C3.1 (+), C4.1 (+), C5.1 (+), C6.1 (+), C7.1 (+), C8.1 (+), C9.1 (+), C14.1 (+), C17.1 (+), C25.2, C26.2, C27.2, GL850G1.1 (AVDD@1), GL850G1.5 (AVDD@2), GL850G1.10 (AVDD@3), GL850G1.16 (DVDD), GL850G1.24 (3V3), J6.2 (VCC), R7.1, U1.1 (IOVDD), U1.10 (IOVDD), U1.22 (IOVDD), U1.33 (IOVDD), U1.42 (IOVDD), U1.43 (ADC_AVDD), U1.44 (VREG_IN), U1.48 (USB_VDD), U1.49 (IOVDD), U3.8 (VCC), U4.2 (VO)
+5V: R13.2, R15.1
CAPS_LOCK_LED: R11.1, U1.40 (GPIO28_ADC2)
COL_0: Esc1.1, Fn1.1, S45.1, S59.1, Tab1.1, U1.6 (GPIO4), `~1.1
COL_1: 1!1.1, Control1.1, F1.1, Q1.1, S46.1, S60.1, U1.7 (GPIO5)
COL_2: 2@1.1, F2.1, Option1.1, S47.1, S61.1, U1.8 (GPIO6), W1.1
COL_3: 3#1.1, Command1.1, E1.1, F3.1, S48.1, S62.1, U1.9 (GPIO7)
COL_4: 4$1.1, F4.1, RKey1.1, S49.1, S63.1, Space1.1, U1.11 (GPIO8)
COL_5: 5%1.1, F5.1, S50.1, S64.1, Space2.1, T1.1, U1.12 (GPIO9)
COL_6: 6^1.1, F6.1, S51.1, S65.1, Space3.1, U1.13 (GPIO10), YKey11.1
COL_7: 7&1.1, F7.1, S52.1, S66.1, Space4.1, U1.14 (GPIO11), UKey1.1
COL_8: 8*1.1, Command2.1, F8.1, I1.1, S53.1, S67.1, U1.15 (GPIO12)
COL_9: 9(1.1, F9.1, O1.1, Option2.1, S54.1, S68.1, U1.16 (GPIO13)
COL_10: 0)1.1, F10.1, Left1.1, P1.1, PgUp1.1, S55.1, S69.1, U1.17 (GPIO14)
COL_11: -_1.1, Down1.1, F11.1, S56.1, S70.1, U1.18 (GPIO15), UP1.1, [{1.1
COL_12: =+1.1, F12.1, PgDown1.1, Right1.1, S57.1, S71.1, U1.27 (GPIO16), ]}1.1
COL_13: Backspace1.1, Del1.1, S58.1, S72.1, U1.28 (GPIO17), \|1.1
COL_14: Backspace2.1, Del2.1, U1.29 (GPIO18)
HOST_USB_D+: GL850G1.26 (DP0), J2.A6 (D+), J2.B6 (D+)
HOST_USB_D-: GL850G1.25 (DM0), J2.A7 (D-), J2.B7 (D-)
HUB_XIN: C20.2, GL850G1.6 (X1), Y2.3
HUB_XOUT: GL850G1.7 (X2), R14.2
unnamed: 0)1.2, 0)D1.2 (A)
unnamed: 1!1.2, 1!D1.2 (A)
unnamed: 2@1.2, 2@D1.2 (A)
unnamed: 3#1.2, 3#D1.2 (A)
unnamed: 4$1.2, 4$D1.2 (A)
unnamed: 5%1.2, 5%D1.2 (A)
unnamed: 6^1.2, 6^D1.2 (A)
unnamed: 7&1.2, 7&D1.2 (A)
unnamed: 8*1.2, 8*D1.2 (A)
unnamed: 9(1.2, 9(D1.2 (A)
unnamed: -_1.2, -_D1.2 (A)
unnamed: =+1.2, =+D1.2 (A)
unnamed: Backspace1.2, BackspaceD1.2 (A)
unnamed: Backspace2.2, BackspaceD2.2 (A)
unnamed: C16.2, R5.1, Y1.1
unnamed: C21.2, R14.1, Y2.1
unnamed: D31.2 (A), Tab1.2
unnamed: D32.2 (A), Q1.2
unnamed: D33.2 (A), W1.2
unnamed: D34.2 (A), E1.2
unnamed: D35.2 (A), RKey1.2
unnamed: D36.2 (A), T1.2
unnamed: D37.2 (A), YKey11.2
unnamed: D38.2 (A), UKey1.2
unnamed: D39.2 (A), I1.2
unnamed: D40.2 (A), O1.2
unnamed: D41.2 (A), P1.2
unnamed: D42.2 (A), [{1.2
unnamed: D43.2 (A), ]}1.2
unnamed: D44.2 (A), \|1.2
unnamed: D45.2 (A), S45.2
unnamed: D46.2 (A), S46.2
unnamed: D47.2 (A), S47.2
unnamed: D48.2 (A), S48.2
unnamed: D49.2 (A), S49.2
unnamed: D50.2 (A), S50.2
unnamed: D51.2 (A), S51.2
unnamed: D52.2 (A), S52.2
unnamed: D53.2 (A), S53.2
unnamed: D54.2 (A), S54.2
unnamed: D55.2 (A), S55.2
unnamed: D56.2 (A), S56.2
unnamed: D57.2 (A), S57.2
unnamed: D58.2 (A), S58.2
unnamed: D59.2 (A), S59.2
unnamed: D60.2 (A), S60.2
unnamed: D61.2 (A), S61.2
unnamed: D62.2 (A), S62.2
unnamed: D63.2 (A), S63.2
unnamed: D64.2 (A), S64.2
unnamed: D65.2 (A), S65.2
unnamed: D66.2 (A), S66.2
unnamed: D67.2 (A), S67.2
unnamed: D68.2 (A), S68.2
unnamed: D69.2 (A), S69.2
unnamed: D70.2 (A), S70.2
unnamed: D71.2 (A), S71.2
unnamed: D72.2 (A), S72.2
unnamed: D73.2 (A), Fn1.2
unnamed: Control1.2, D74.2 (A)
unnamed: D75.2 (A), Option1.2
unnamed: Command1.2, D76.2 (A)
unnamed: D77.2 (A), Space1.2
unnamed: D78.2 (A), Space2.2
unnamed: D79.2 (A), Space3.2
unnamed: D80.2 (A), Space4.2
unnamed: Command2.2, D81.2 (A)
unnamed: D82.2 (A), Option2.2
unnamed: D84.2 (A), PgUp1.2
unnamed: D85.2 (A), UP1.2
unnamed: D86.2 (A), PgDown1.2
unnamed: D87.2 (A), Left1.2
unnamed: D88.2 (A), Down1.2
unnamed: D89.2 (A), Right1.2
unnamed: D91.2 (A), R11.2
unnamed: Del1.2, DelD1.2 (A)
unnamed: Del2.2, DelD2.2 (A)
unnamed: Esc1.2, EscD1.2 (A)
unnamed: F1.2, F1D1.2 (A)
unnamed: F2.2, F2D1.2 (A)
unnamed: F3.2, F3D1.2 (A)
unnamed: F4.2, F4D1.2 (A)
unnamed: F5.2, F5D1.2 (A)
unnamed: F6.2, F6D1.2 (A)
unnamed: F7.2, F7D1.2 (A)
unnamed: F8.2, F8D1.2 (A)
unnamed: F9.2, F9D1.2 (A)
unnamed: F10.2, F10D1.2 (A)
unnamed: F11.2, F11D1.2 (A)
unnamed: F12.2, F12D1.2 (A)
unnamed: GL850G1.4 (RREF), R1.2
unnamed: GL850G1.21 (~OVCUR1), R12.1, R13.1
unnamed: C22.2, GL850G1.13 (~RESET), R15.2
unnamed: J2.A5 (CC1), R8.1
unnamed: J2.B5 (CC2), R9.1
unnamed: J6.3 (SCL), R17.2
unnamed: J6.4 (SDA), R16.2
unnamed: R6.2, SW1.1
unnamed: R4.2, U1.46 (USB_DM)
unnamed: R3.2, U1.47 (USB_DP)
unnamed: `~1.2, `~D1.2 (A)
OLED_SCL: R17.1, U1.39 (GPIO27_ADC1)
OLED_SDA: R16.1, U1.38 (GPIO26_ADC0)
PORT1_USB_D+: GL850G1.28 (DP1), J3.3 (D+)
PORT1_USB_D-: GL850G1.27 (DM1), J3.2 (D-)
PORT2_USB_D+: GL850G1.12 (DP4), J4.3 (D+)
PORT2_USB_D-: GL850G1.11 (DM4), J4.2 (D-)
QSPI_SCLK: U1.52 (QSPI_SCLK), U3.6 (CLK)
QSPI_SD0: U1.53 (QSPI_SD0), U3.5 (DI/IO_{0})
QSPI_SD1: U1.55 (QSPI_SD1), U3.2 (DO/IO_{1})
QSPI_SD2: U1.54 (QSPI_SD2), U3.3 (~WP/IO_{2})
QSPI_SD3: U1.51 (QSPI_SD3), U3.7 (~HOLD/~RESET/IO_{3})
QSPI_SS: R6.1, R7.2, U1.56 (QSPI_SS), U3.1 (~CS)
ROW_0: DelD1.1 (K), DelD2.1 (K), EscD1.1 (K), F1D1.1 (K), F2D1.1 (K), F3D1.1 (K), F4D1.1 (K), F5D1.1 (K), F6D1.1 (K), F7D1.1 (K), F8D1.1 (K), F9D1.1 (K), F10D1.1 (K), F11D1.1 (K), F12D1.1 (K), U1.30 (GPIO19)
ROW_1: 0)D1.1 (K), 1!D1.1 (K), 2@D1.1 (K), 3#D1.1 (K), 4$D1.1 (K), 5%D1.1 (K), 6^D1.1 (K), 7&D1.1 (K), 8*D1.1 (K), 9(D1.1 (K), -_D1.1 (K), =+D1.1 (K), BackspaceD1.1 (K), BackspaceD2.1 (K), U1.31 (GPIO20), `~D1.1 (K)
ROW_2: D31.1 (K), D32.1 (K), D33.1 (K), D34.1 (K), D35.1 (K), D36.1 (K), D37.1 (K), D38.1 (K), D39.1 (K), D40.1 (K), D41.1 (K), D42.1 (K), D43.1 (K), D44.1 (K), U1.32 (GPIO21)
ROW_3: D45.1 (K), D46.1 (K), D47.1 (K), D48.1 (K), D49.1 (K), D50.1 (K), D51.1 (K), D52.1 (K), D53.1 (K), D54.1 (K), D55.1 (K), D56.1 (K), D57.1 (K), D58.1 (K), U1.34 (GPIO22)
ROW_4: D59.1 (K), D60.1 (K), D61.1 (K), D62.1 (K), D63.1 (K), D64.1 (K), D65.1 (K), D66.1 (K), D67.1 (K), D68.1 (K), D69.1 (K), D70.1 (K), D71.1 (K), D72.1 (K), U1.35 (GPIO23)
ROW_5: D73.1 (K), D74.1 (K), D75.1 (K), D76.1 (K), D77.1 (K), D78.1 (K), D79.1 (K), D80.1 (K), D81.1 (K), D82.1 (K), D84.1 (K), D85.1 (K), D86.1 (K), U1.36 (GPIO24)
ROW_6: D87.1 (K), D88.1 (K), D89.1 (K), U1.37 (GPIO25)
RP2040_USB_D+: GL850G1.9 (DP3), R3.1
RP2040_USB_D-: GL850G1.8 (DM3), R4.1
TEST: C1.2 (-), C2.2 (-), C3.2 (-), C4.2 (-), C5.2 (-), C6.2 (-), C7.2 (-), C8.2 (-), C9.2 (-), C10.2 (-), C11.2 (-), C12.2 (-), C13.2 (-), C14.2 (-), C15.1, C16.1, C17.2 (-), C20.1, C21.1, C22.1, C23.1, C24.1, C25.1, C26.1, C27.1, D91.1 (K), GL850G1.14 (TEST), GL850G1.15 (GND), J1.1, J2.A1 (GND), J2.A12 (GND), J2.B1 (GND), J2.B12 (GND), J2.S1 (SHIELD), J3.4 (GND), J3.5 (Shield), J4.4 (GND), J4.5 (Shield), J6.1 (GND), R1.1, R8.2, R9.2, R12.2, SW1.2, U1.19 (TESTEN), U1.57 (GND), U3.4 (GND), U4.1 (GND), Y1.2, Y1.4, Y2.2, Y2.4
VBUS: C13.1 (+), C23.2, C24.2, GL850G1.23 (5V), J2.A4 (VBUS), J2.A9 (VBUS), J2.B4 (VBUS), J2.B9 (VBUS), J3.1 (VBUS), J4.1 (VBUS), J5.2, U4.3 (VI)
XIN: C15.2, U1.20 (XIN), Y1.3
XLR_CSn: J5.1, U1.3 (GPIO1)
XLR_RX: J5.3, U1.2 (GPIO0)
XLR_SCK: J1.2, U1.4 (GPIO2)
XLR_TX: J1.3, U1.5 (GPIO3)
XOUT: R5.2, U1.21 (XOUT)

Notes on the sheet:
Caps Lock LED
OLED panel
USB Hub
Modular XLR connection circuit
MCU Functions - RP2040
Main keyboard matrix

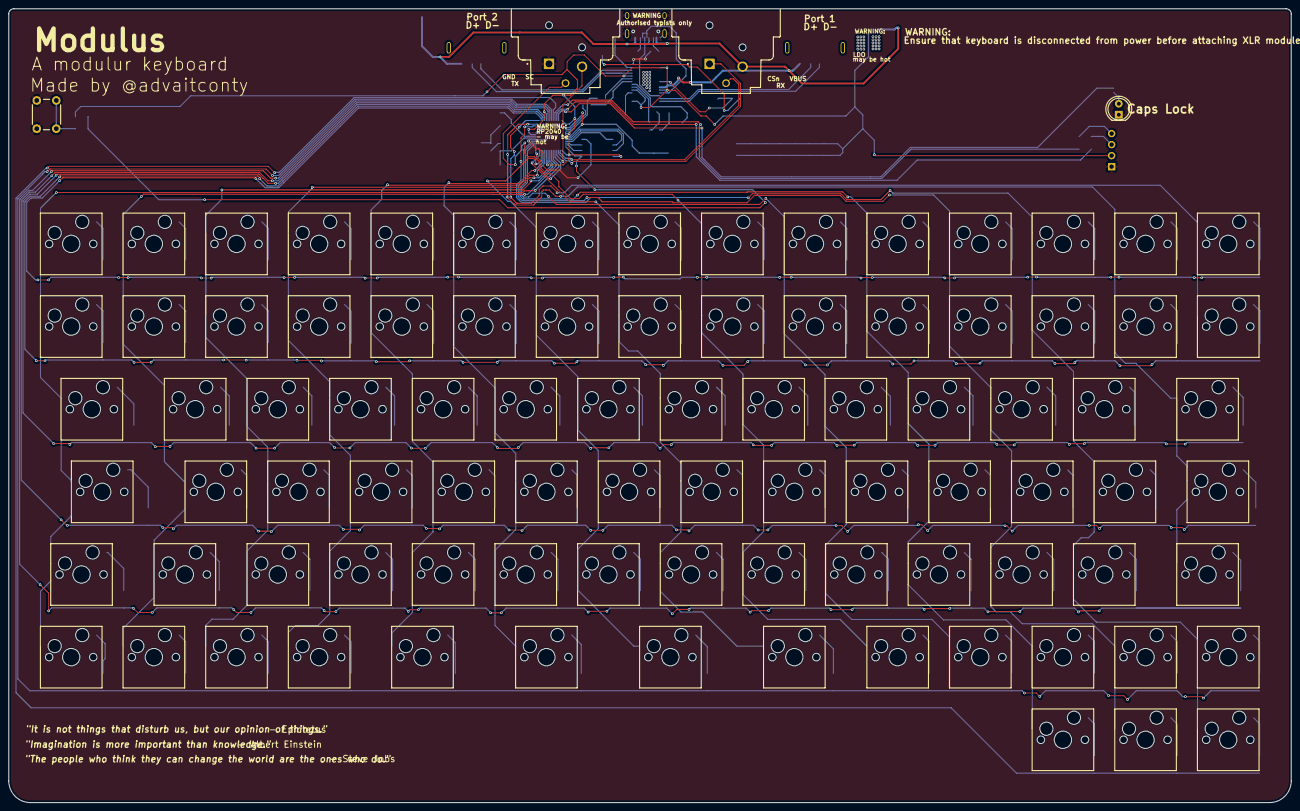
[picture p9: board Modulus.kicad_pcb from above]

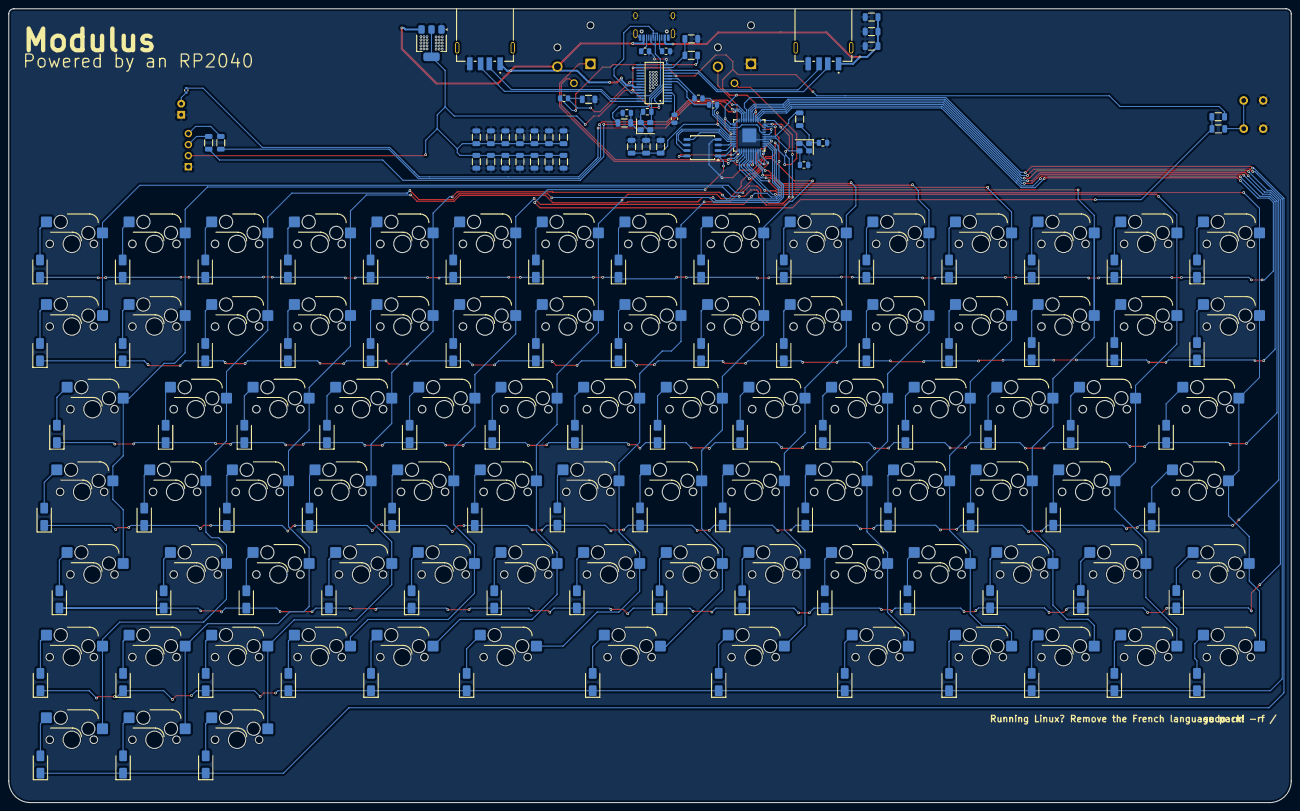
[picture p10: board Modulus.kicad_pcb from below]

Board: 2 copper layers, 295.6 x 183.0 mm, 230 parts (137 on the bottom side), 153 nets.

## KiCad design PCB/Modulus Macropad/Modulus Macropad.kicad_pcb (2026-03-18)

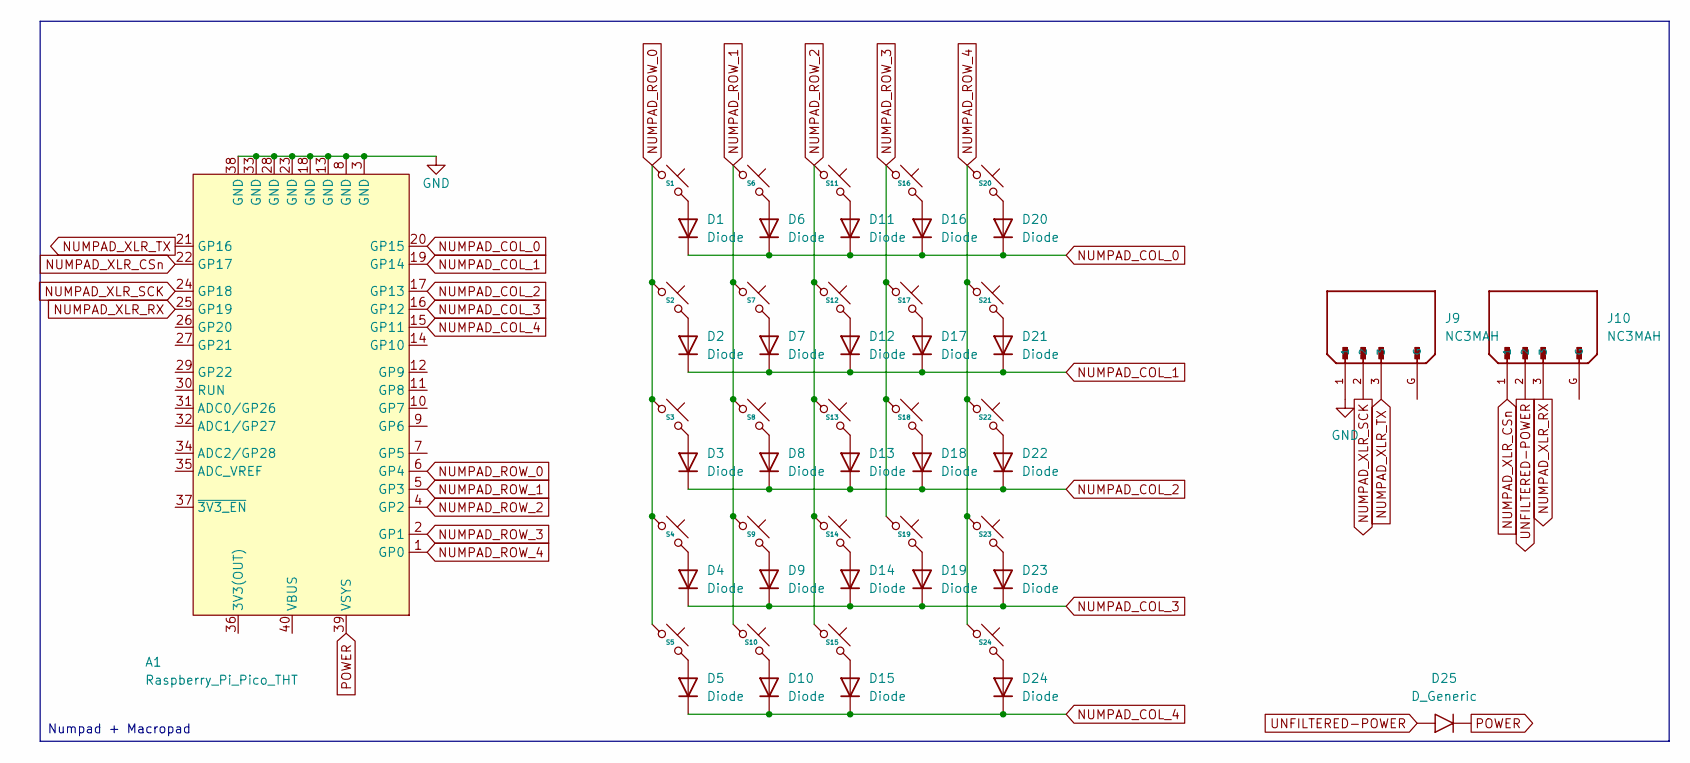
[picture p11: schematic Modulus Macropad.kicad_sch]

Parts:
A1: Raspberry_Pi_Pico_THT; raspberry_pi_pico_THT
D1, D2, D3, D4, D5, D6, D7, D8, D9, D10, D11, D12, D13, D14, D15, D16, D17, D18, D19, D20, D21, D22, D23, D24: Diode; D_SMA; JLCPCB Part # C81598
D25: D_Generic; D_SMA
J9, J10: NC3MAH; NEUTRIK_NC3MAH; PARTREV 30.03.09
S1, S2, S3, S4, S5, S6, S7, S8, S9, S10, S11, S12, S13, S14, S15, S16, S17, S20, S21, S22, S23, S24: SW_Hotswap_Kailh_MX_1.00u
S18, S19: SW_Hotswap_Kailh_MX_1.50u_90deg

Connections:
NUMPAD_COL_0: A1.20 (GP15), D1.1 (K), D6.1 (K), D11.1 (K), D16.1 (K), D20.1 (K)
NUMPAD_COL_1: A1.19 (GP14), D2.1 (K), D7.1 (K), D12.1 (K), D17.1 (K), D21.1 (K)
NUMPAD_COL_2: A1.17 (GP13), D3.1 (K), D8.1 (K), D13.1 (K), D18.1 (K), D22.1 (K)
NUMPAD_COL_3: A1.16 (GP12), D4.1 (K), D9.1 (K), D14.1 (K), D19.1 (K), D23.1 (K)
NUMPAD_COL_4: A1.15 (GP11), D5.1 (K), D10.1 (K), D15.1 (K), D24.1 (K)
NUMPAD_ROW_0: A1.6 (GP4), S1.1, S2.1, S3.1, S4.1, S5.1
NUMPAD_ROW_1: A1.5 (GP3), S6.1, S7.1, S8.1, S9.1, S10.1
NUMPAD_ROW_2: A1.4 (GP2), S11.1, S12.1, S13.1, S14.1, S15.1
NUMPAD_ROW_3: A1.2 (GP1), S16.1, S17.1, S18.1, S19.1
NUMPAD_ROW_4: A1.1 (GP0), S20.1, S21.1, S22.1, S23.1, S24.1
NUMPAD_XLR_CSn: A1.22 (GP17), J10.1
NUMPAD_XLR_RX: A1.25 (GP19), J10.3
NUMPAD_XLR_SCK: A1.24 (GP18), J9.2
NUMPAD_XLR_TX: A1.21 (GP16), J9.3
unnamed: D1.2 (A), S1.2
unnamed: D2.2 (A), S2.2
unnamed: D3.2 (A), S3.2
unnamed: D4.2 (A), S4.2
unnamed: D5.2 (A), S5.2
unnamed: D6.2 (A), S6.2
unnamed: D7.2 (A), S7.2
unnamed: D8.2 (A), S8.2
unnamed: D9.2 (A), S9.2
unnamed: D10.2 (A), S10.2
unnamed: D11.2 (A), S11.2
unnamed: D12.2 (A), S12.2
unnamed: D13.2 (A), S13.2
unnamed: D14.2 (A), S14.2
unnamed: D15.2 (A), S15.2
unnamed: D16.2 (A), S16.2
unnamed: D17.2 (A), S17.2
unnamed: D18.2 (A), S18.2
unnamed: D19.2 (A), S19.2
unnamed: D20.2 (A), S20.2
unnamed: D21.2 (A), S21.2
unnamed: D22.2 (A), S22.2
unnamed: D23.2 (A), S23.2
unnamed: D24.2 (A), S24.2
POWER: A1.39 (VSYS), D25.1 (K)
TEST: A1.3 (GND), A1.8 (GND), A1.13 (GND), A1.18 (GND), A1.23 (GND), A1.28 (GND), A1.33 (GND), A1.38 (GND), J9.1
UNFILTERED-POWER: D25.2 (A), J10.2

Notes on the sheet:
Numpad + Macropad

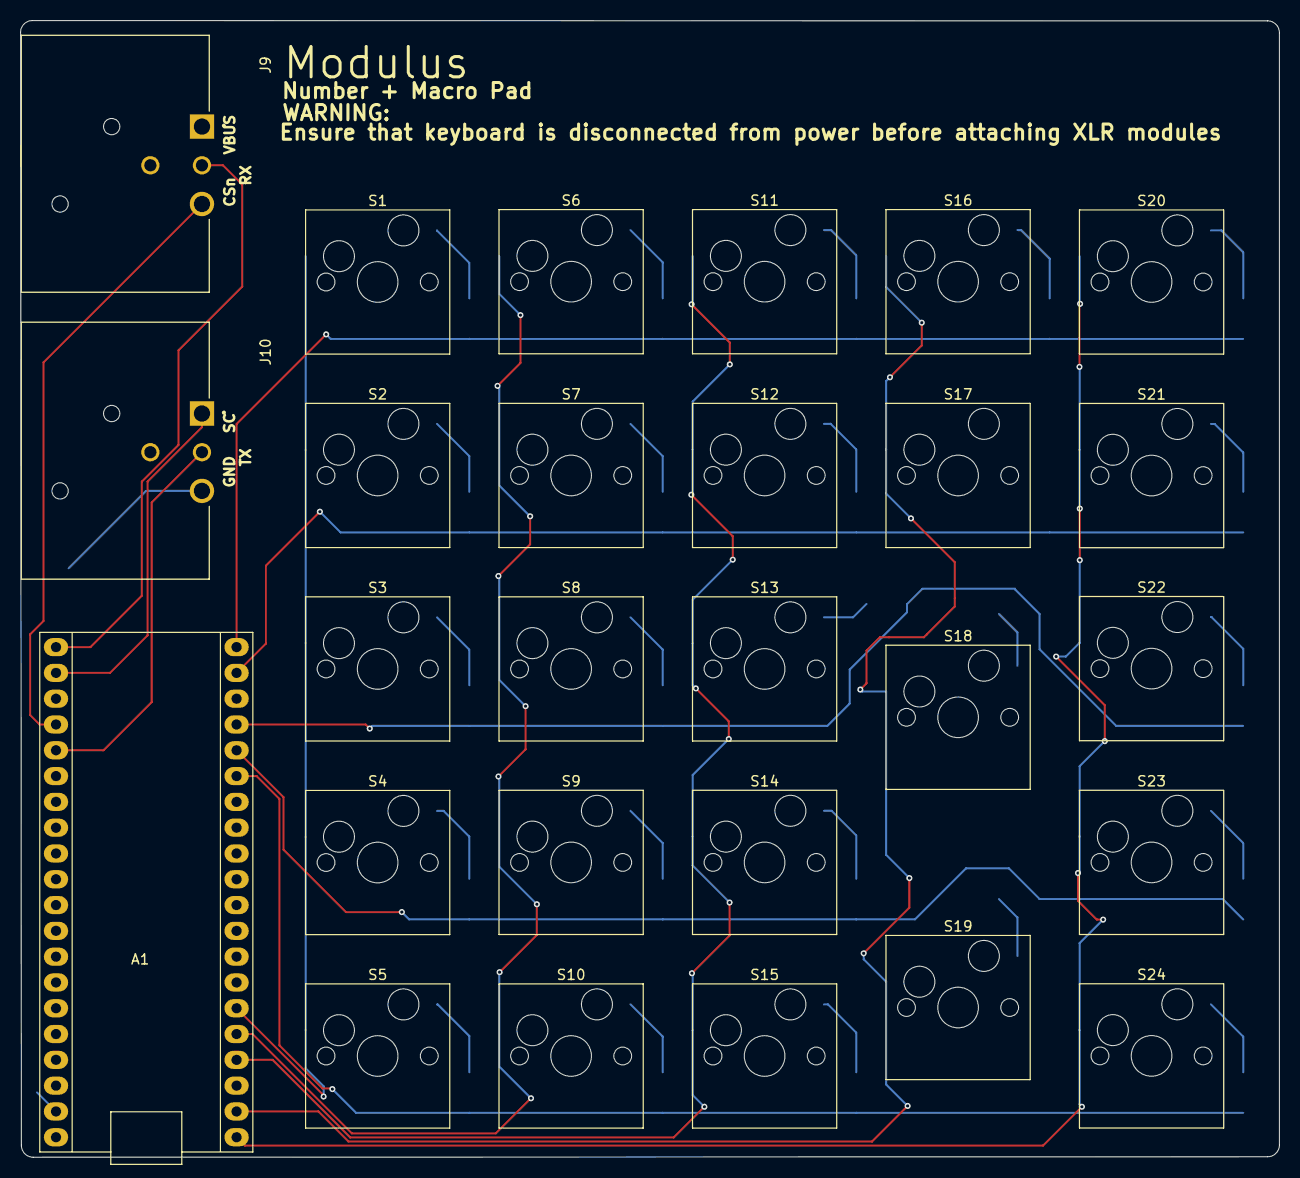
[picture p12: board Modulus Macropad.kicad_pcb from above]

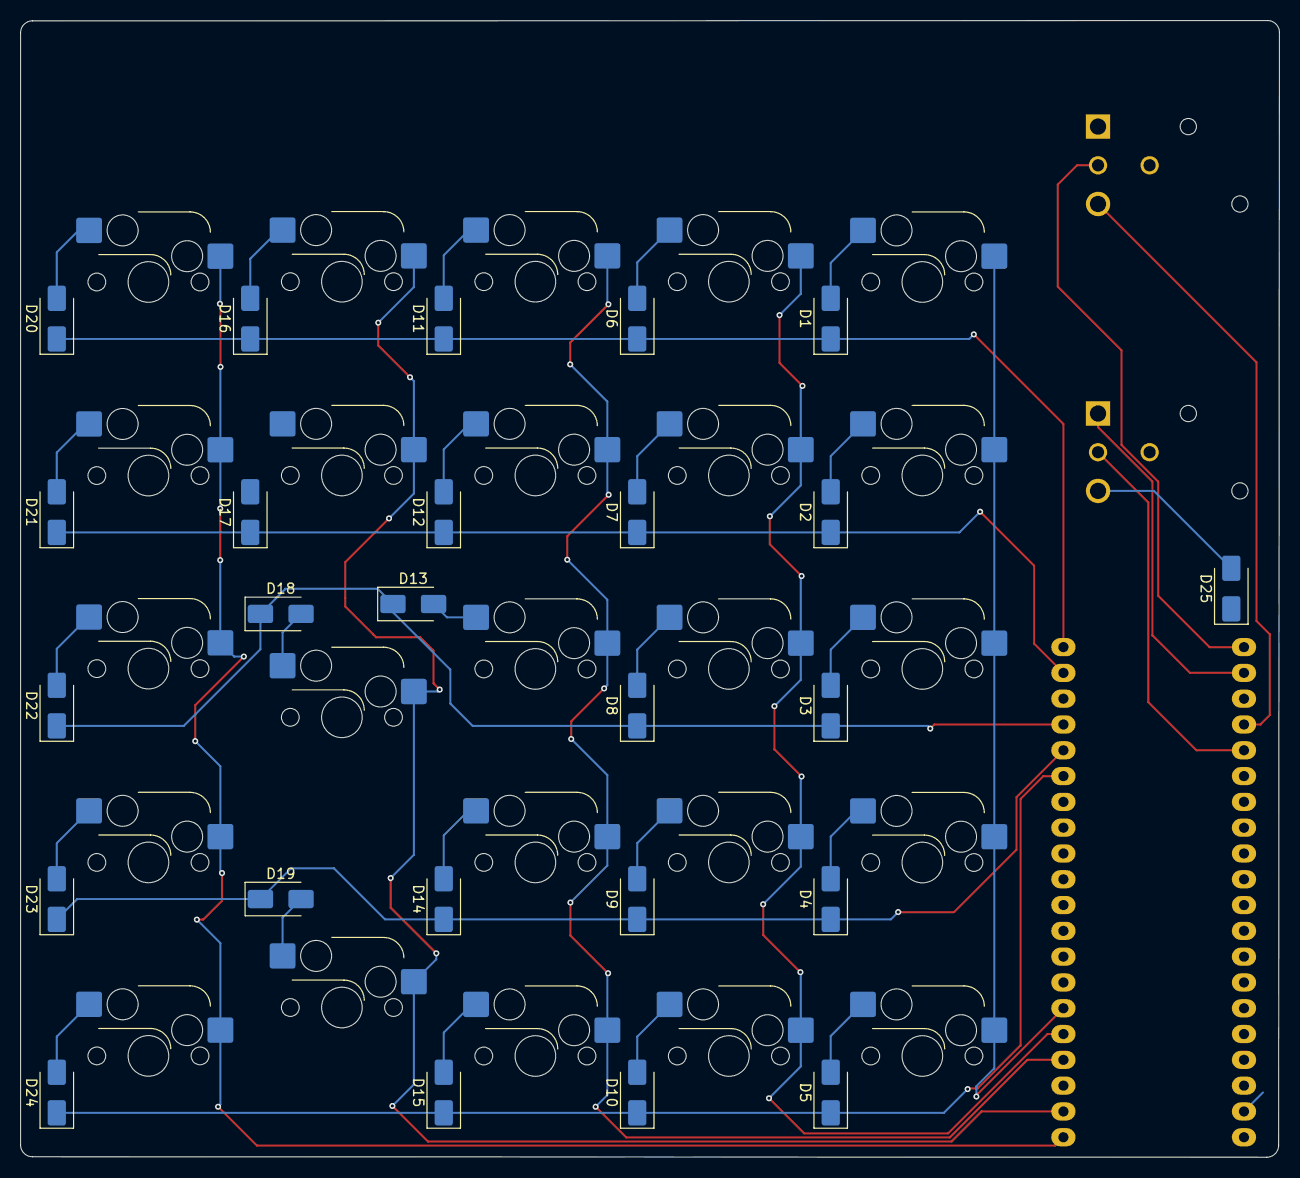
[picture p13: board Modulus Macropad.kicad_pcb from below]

Board: 2 copper layers, 123.9 x 111.9 mm, 52 parts (25 on the bottom side), 41 nets.

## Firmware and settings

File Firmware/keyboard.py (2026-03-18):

"""
KMK Firmware — Custom 89-key keyboard (RP2040, built-in)
=========================================================
Matrix : 7 rows (ROW_0..ROW_6) × 15 cols (COL_0..COL_14)
SPI    : MASTER — receives key event strings FROM the macropad Pico.

The main keyboard is the USB HID device. The macropad Pico is a SPI slave;
it scans its own matrix and sends key events back to this board as SPI
messages, which are then injected as HID keystrokes here.

SPI wiring (connect these four wires between the two boards):
  This board (Master)      Macropad Pico (Slave)
  ────────────────────     ─────────────────────
  GP18  SCK         ───►  GP18  SCK
  GP19  MOSI        ───►  GP19  MOSI  (unused by slave, tie low or leave)
  GP16  MISO (RX)   ◄───  GP16  MISO  (slave sends here)
  GP17  CS          ───►  GP17  CS    (active LOW)
  GND               ───   GND         (MUST be common ground)

Protocol (newline-terminated strings sent by macropad over MISO):
  Keybind   → "CTRL+C\\n", "CTRL+SHIFT+T\\n", "ALT+F4\\n"
  Plain text → "Hello\\n"
  Numpad key → "P7\\n", "PPLS\\n", "PENT\\n"  (named key tokens)
  Idle byte  → 0xFF  (macropad sends this when no key is pending)

Keyboard matrix wiring assumptions (adjust GP numbers to match your PCB):
  ROW_0..ROW_6  →  GP0..GP6
  COL_0..COL_14 →  GP7–GP15, GP20–GP22, GP26–GP28
"""

import board
import busio
import digitalio

from kmk.kmk_keyboard import KMKKeyboard
from kmk.keys import KC
from kmk.scanners import DiodeOrientation
from kmk.scanners.keypad import MatrixScanner
from kmk.modules.layers import Layers

# ──────────────────────────────────────────────
# 1. KEYBOARD OBJECT
# ──────────────────────────────────────────────
keyboard = KMKKeyboard()

# ──────────────────────────────────────────────
# 2. MATRIX PINS
# ──────────────────────────────────────────────
keyboard.matrix = MatrixScanner(
    column_pins=(
        board.GP7,  board.GP8,  board.GP9,  board.GP10, board.GP11,
        board.GP12, board.GP13, board.GP14, board.GP15, board.GP20,
        board.GP21, board.GP22, board.GP26, board.GP27, board.GP28,
    ),
    row_pins=(
        board.GP0, board.GP1, board.GP2, board.GP3,
        board.GP4, board.GP5, board.GP6,
    ),
    diode_orientation=DiodeOrientation.COL2ROW,
)

# ──────────────────────────────────────────────
# 3. MODULES
# ──────────────────────────────────────────────
keyboard.modules.append(Layers())

# ──────────────────────────────────────────────
# 4. KEYMAP
# ──────────────────────────────────────────────
XXXXXXX = KC.NO

keyboard.keymap = [
    # ── Layer 0 — Base ──────────────────────────────────────────────────────
    [
        # ROW_0  (15 keys)
        KC.ESC,  KC.F1,   KC.F2,   KC.F3,   KC.F4,   KC.F5,   KC.F6,
        KC.F7,   KC.F8,   KC.F9,   KC.F10,  KC.F11,  KC.F12,  KC.DEL,  KC.DEL,

        # ROW_1  (15 keys)
        KC.GRV,  KC.N1,   KC.N2,   KC.N3,   KC.N4,   KC.N5,   KC.N6,
        KC.N7,   KC.N8,   KC.N9,   KC.N0,   KC.MINS, KC.EQL,  KC.BSPC, KC.BSPC,

        # ROW_2  (14 keys; col14 unpopulated)
        KC.TAB,  KC.Q,    KC.W,    KC.E,    KC.R,    KC.T,    KC.Y,
        KC.U,    KC.I,    KC.O,    KC.P,    KC.LBRC, KC.RBRC, KC.BSLS, XXXXXXX,

        # ROW_3  (14 keys; col14 unpopulated)
        KC.CAPS, KC.A,    KC.S,    KC.D,    KC.F,    KC.G,    KC.H,
        KC.J,    KC.K,    KC.L,    KC.SCLN, KC.QUOT, KC.ENT,  KC.ENT,  XXXXXXX,

        # ROW_4  (12 keys; cols 12-14 unpopulated)
        KC.LSFT, KC.Z,    KC.X,    KC.C,    KC.V,    KC.B,    KC.N,
        KC.M,    KC.COMM, KC.DOT,  KC.SLSH, KC.RSFT, XXXXXXX, XXXXXXX, XXXXXXX,

        # ROW_5  (13 keys; cols 13-14 unpopulated)
        KC.MO(1), KC.LCTL, KC.LALT, KC.LGUI,
        KC.SPC,  KC.SPC,  KC.SPC,  KC.SPC,
        KC.RGUI, KC.RALT, KC.PGUP, KC.UP,   KC.PGDN, XXXXXXX, XXXXXXX,

        # ROW_6  (3 keys; only cols 9-11 populated)
        XXXXXXX, XXXXXXX, XXXXXXX, XXXXXXX, XXXXXXX, XXXXXXX, XXXXXXX,
        XXXXXXX, XXXXXXX, KC.LEFT, KC.DOWN, KC.RGHT, XXXXXXX, XXXXXXX, XXXXXXX,
    ],

    # ── Layer 1 — Fn ────────────────────────────────────────────────────────
    [
        # ROW_0 — media / brightness on Fn
        KC.TRNS, KC.BRID, KC.BRIU, KC.TRNS, KC.TRNS, KC.TRNS, KC.TRNS,
        KC.MPRV, KC.MPLY, KC.MNXT, KC.MUTE, KC.VOLD, KC.VOLU, KC.TRNS, KC.TRNS,

        *[KC.TRNS] * 15,  # ROW_1
        *[KC.TRNS] * 15,  # ROW_2
        *[KC.TRNS] * 15,  # ROW_3
        *[KC.TRNS] * 15,  # ROW_4
        *[KC.TRNS] * 15,  # ROW_5
        *[KC.TRNS] * 15,  # ROW_6
    ],
]

# ──────────────────────────────────────────────
# 5. SPI MASTER — receives key events from macropad Pico
# ──────────────────────────────────────────────

_SPI_BAUDRATE = 500_000  # 500 kHz — conservative for bit-bang slave

# Hardware SPI1: SCK=GP18, MOSI=GP19 (unused), MISO=GP16
_spi = busio.SPI(clock=board.GP18, MOSI=board.GP19, MISO=board.GP16)
_cs  = digitalio.DigitalInOut(board.GP17)
_cs.direction = digitalio.Direction.OUTPUT
_cs.value = True  # idle HIGH

_spi_rx_buf = []  # accumulate characters until newline

# ── Key name → KC lookup (includes numpad keys for macropad) ────────────────
_MOD_MAP = {
    "CTRL": KC.LCTL, "CONTROL": KC.LCTL,
    "SHIFT": KC.LSFT,
    "ALT": KC.LALT, "OPTION": KC.LALT,
    "GUI": KC.LGUI, "CMD": KC.LGUI, "WIN": KC.LGUI,
    "RCTRL": KC.RCTL, "RSHIFT": KC.RSFT, "RALT": KC.RALT, "RGUI": KC.RGUI,
}

_KEY_NAME_MAP = {
    # Navigation / editing
    "ESC": KC.ESC,       "TAB": KC.TAB,      "ENTER": KC.ENT,   "RETURN": KC.ENT,
    "SPACE": KC.SPC,     "BSPC": KC.BSPC,    "BACKSPACE": KC.BSPC,
    "DEL": KC.DEL,       "DELETE": KC.DEL,
    "UP": KC.UP,         "DOWN": KC.DOWN,    "LEFT": KC.LEFT,   "RIGHT": KC.RGHT,
    "PGUP": KC.PGUP,     "PGDN": KC.PGDN,    "HOME": KC.HOME,   "END": KC.END,
    "INS": KC.INS,       "INSERT": KC.INS,
    "CAPS": KC.CAPS,     "CAPSLOCK": KC.CAPS,
    "PRTSC": KC.PSCR,    "PRINTSCREEN": KC.PSCR,
    # Function keys
    "F1": KC.F1,  "F2": KC.F2,  "F3": KC.F3,  "F4": KC.F4,
    "F5": KC.F5,  "F6": KC.F6,  "F7": KC.F7,  "F8": KC.F8,
    "F9": KC.F9,  "F10": KC.F10, "F11": KC.F11, "F12": KC.F12,
    # Media
    "MUTE": KC.MUTE,  "VOLU": KC.VOLU,  "VOLD": KC.VOLD,
    "MPLY": KC.MPLY,  "MNXT": KC.MNXT,  "MPRV": KC.MPRV,
    "BRID": KC.BRID,  "BRIU": KC.BRIU,  "PSCR": KC.PSCR,
    # Numpad keys (sent by macropad)
    "NLCK": KC.NLCK,  "NUMLOCK": KC.NLCK,
    "PSLS": KC.PSLS,  "PAST": KC.PAST,  "PMNS": KC.PMNS,
    "PPLS": KC.PPLS,  "PENT": KC.PENT,  "PDOT": KC.PDOT,
    "P0": KC.P0, "P1": KC.P1, "P2": KC.P2, "P3": KC.P3, "P4": KC.P4,
    "P5": KC.P5, "P6": KC.P6, "P7": KC.P7, "P8": KC.P8, "P9": KC.P9,
}

def _ascii_to_kc(ch):
    if ch in ("\n", "\r"): return KC.ENT
    if ch == "\t":         return KC.TAB
    if ch == " ":          return KC.SPC
    if ch.isupper():
        k = getattr(KC, ch, None)
        return KC.LSFT(k) if k else None
    if ch.islower():       return getattr(KC, ch.upper(), None)
    if ch.isdigit():       return getattr(KC, "N" + ch, None)
    return {
        "!": KC.LSFT(KC.N1),  "@": KC.LSFT(KC.N2),  "#": KC.LSFT(KC.N3),
        "$": KC.LSFT(KC.N4),  "%": KC.LSFT(KC.N5),  "^": KC.LSFT(KC.N6),
        "&": KC.LSFT(KC.N7),  "*": KC.LSFT(KC.N8),  "(": KC.LSFT(KC.N9),
        ")": KC.LSFT(KC.N0),  "-": KC.MINS,          "_": KC.LSFT(KC.MINS),
        "=": KC.EQL,          "+": KC.LSFT(KC.EQL),  "[": KC.LBRC,
        "{": KC.LSFT(KC.LBRC),"]": KC.RBRC,          "}": KC.LSFT(KC.RBRC),
        "\\": KC.BSLS,        "|": KC.LSFT(KC.BSLS), ";": KC.SCLN,
        ":": KC.LSFT(KC.SCLN),"'": KC.QUOT,          '"': KC.LSFT(KC.QUOT),
        ",": KC.COMM,         "<": KC.LSFT(KC.COMM), ".": KC.DOT,
        ">": KC.LSFT(KC.DOT), "/": KC.SLSH,          "?": KC.LSFT(KC.SLSH),
        "`": KC.GRV,          "~": KC.LSFT(KC.GRV),
    }.get(ch, None)

def _parse_command(raw):
    text = raw.strip()
    if not text:
        return []
    upper = text.upper()
    parts = upper.split("+")
    if len(parts) > 1:
        mods, key = [], None
        for p in parts:
            p = p.strip()
            if p in _MOD_MAP:        mods.append(_MOD_MAP[p])
            elif p in _KEY_NAME_MAP: key = _KEY_NAME_MAP[p]
            elif len(p) == 1:        key = _ascii_to_kc(p.lower())
        if key is not None:
            for mod in reversed(mods):
                key = mod(key)
            return [key]
    # Single named key (e.g. "P7", "PPLS", "PENT")
    if upper in _KEY_NAME_MAP:
        return [_KEY_NAME_MAP[upper]]
    # Plain ASCII string
    return [kc for ch in text if (kc := _ascii_to_kc(ch)) is not None]

def _inject_keys(key_list):
    for key in key_list:
        keyboard.hid.register_key(key)
        keyboard.hid.send()
        keyboard.hid.unregister_key(key)
        keyboard.hid.send()

def _poll_spi():
    """Read one byte from macropad per call. 0xFF = slave idle (skip)."""
    try:
        if not _spi.try_lock():
            return
        _spi.configure(baudrate=_SPI_BAUDRATE, phase=0, polarity=0)
        _cs.value = False
        rx = bytearray(1)
        _spi.readinto(rx, write_value=0xFF)
        _cs.value = True
        _spi.unlock()

        b = rx[0]
        if b == 0xFF:   # idle
            return
        ch = chr(b)
        if ch in ("\n", "\r"):
            line = "".join(_spi_rx_buf)
            _spi_rx_buf.clear()
            if line:
                _inject_keys(_parse_command(line))
        else:
            _spi_rx_buf.append(ch)
    except Exception:
        _cs.value = True
        try:   _spi.unlock()
        except Exception: pass

# ──────────────────────────────────────────────
# 6. MAIN LOOP
# ──────────────────────────────────────────────
if __name__ == "__main__":
    keyboard._init()
    while True:
        keyboard._main_task()
        _poll_spi()

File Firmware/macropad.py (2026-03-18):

"""
KMK Firmware — Macropad (Pi Pico, separate MCU)
================================================
Matrix : 5 rows (NUMPAD_ROW_0..4) × 5 cols (NUMPAD_COL_0..4)
         24 keys total (ROW_4/COL_3 unpopulated)
SPI    : SLAVE — sends key event strings TO the main keyboard RP2040.

The macropad does NOT enumerate as a USB HID device for keystrokes —
the main keyboard handles all HID. When a key is pressed here, this
firmware encodes it as a newline-terminated string and transmits it
over SPI MISO back to the master.

SPI wiring (same four wires, macropad side):
  Macropad Pico (Slave)     Main keyboard (Master)
  ─────────────────────     ──────────────────────
  GP18  SCK           ◄───  GP18  SCK
  GP19  MOSI          ◄───  GP19  MOSI  (not used, tie/leave)
  GP16  MISO (TX)     ───►  GP16  MISO  (master reads here)
  GP17  CS            ◄───  GP17  CS    (active LOW)
  GND                 ───   GND

Protocol this board sends (over MISO, newline-terminated):
  Numpad key  → "P7\\n", "PPLS\\n", "PENT\\n", "NLCK\\n" …
  Keybind     → "CTRL+C\\n", "MUTE\\n", "BRIU\\n" …

Because CircuitPython has no hardware SPI slave mode, this firmware
uses a software (bit-bang) SPI slave on the same pins.
MISO is driven as an output; SCK and CS are inputs.

Matrix wiring assumptions (adjust GP numbers to match your PCB):
  NUMPAD_ROW_0..4  →  GP0..GP4
  NUMPAD_COL_0..4  →  GP5..GP9
"""

import board
import digitalio
import time

from kmk.kmk_keyboard import KMKKeyboard
from kmk.keys import KC
from kmk.scanners import DiodeOrientation
from kmk.scanners.keypad import MatrixScanner
from kmk.modules.layers import Layers
from kmk.handlers.sequences import send_string

# ──────────────────────────────────────────────
# 1. KEYBOARD OBJECT
#    The Pico still uses KMK for clean matrix scanning.
#    Key "actions" are SPI transmissions rather than HID reports,
#    achieved via custom KC.make_key handlers below.
# ──────────────────────────────────────────────
keyboard = KMKKeyboard()

# ──────────────────────────────────────────────
# 2. MATRIX PINS
# ──────────────────────────────────────────────
keyboard.matrix = MatrixScanner(
    column_pins=(
        board.GP5,   # NUMPAD_COL_0
        board.GP6,   # NUMPAD_COL_1
        board.GP7,   # NUMPAD_COL_2
        board.GP8,   # NUMPAD_COL_3
        board.GP9,   # NUMPAD_COL_4
    ),
    row_pins=(
        board.GP0,   # NUMPAD_ROW_0
        board.GP1,   # NUMPAD_ROW_1
        board.GP2,   # NUMPAD_ROW_2
        board.GP3,   # NUMPAD_ROW_3
        board.GP4,   # NUMPAD_ROW_4
    ),
    diode_orientation=DiodeOrientation.COL2ROW,
)

# ──────────────────────────────────────────────
# 3. MODULES
# ──────────────────────────────────────────────
keyboard.modules.append(Layers())

# ──────────────────────────────────────────────
# 4. SOFTWARE SPI SLAVE TRANSMITTER
#    Drives MISO out, samples SCK and CS as inputs.
#    Sends one byte per SCK rising edge (MSB first, Mode 0).
# ──────────────────────────────────────────────
_MISO_PIN = board.GP16   # output → master MISO
_SCK_PIN  = board.GP18   # input  ← master SCK
_CS_PIN   = board.GP17   # input  ← master CS (active LOW)

_miso = digitalio.DigitalInOut(_MISO_PIN)
_miso.direction = digitalio.Direction.OUTPUT
_miso.value = True   # idle HIGH (MISO idles high)

_sck_in = digitalio.DigitalInOut(_SCK_PIN)
_sck_in.direction = digitalio.Direction.INPUT
_sck_in.pull = digitalio.Pull.UP

_cs_in = digitalio.DigitalInOut(_CS_PIN)
_cs_in.direction = digitalio.Direction.INPUT
_cs_in.pull = digitalio.Pull.UP

# Queue of strings waiting to be sent to the master
_tx_queue = []

def _spi_send_byte(b: int):
    """
    Clock out one byte MSB-first on MISO, synchronised to master SCK.
    Blocks until all 8 bits are sent or CS deasserts.
    """
    for bit_pos in range(7, -1, -1):
        _miso.value = bool(b & (1 << bit_pos))
        # Wait for SCK rising edge
        while _sck_in.value:   # wait for LOW first
            if _cs_in.value: return
        while not _sck_in.value:  # wait for HIGH (rising edge)
            if _cs_in.value: return
    _miso.value = True  # return MISO high after byte

def _spi_transmit(msg: str):
    """
    Transmit a newline-terminated string to the master when CS is LOW.
    Waits up to ~5 ms for CS to assert; drops message if master isn't ready.
    """
    # Wait for master to assert CS
    deadline = time.monotonic() + 0.005
    while _cs_in.value:
        if time.monotonic() > deadline:
            return   # master not ready, drop
    for ch in (msg + "\n"):
        _spi_send_byte(ord(ch))
    # Send idle byte so master clock cycle completes cleanly
    _spi_send_byte(0xFF)

def _queue_key(msg: str):
    """Add a key message to the transmit queue."""
    _tx_queue.append(msg)

def _flush_tx():
    """Send one queued message per call (called each main loop iteration)."""
    if _tx_queue:
        _spi_transmit(_tx_queue.pop(0))

# ──────────────────────────────────────────────
# 5. CUSTOM KEY FACTORY
#    make_spi_key("P7") creates a KC-compatible key that, on press,
#    queues "P7\n" for SPI transmission to the master.
# ──────────────────────────────────────────────
def make_spi_key(token: str):
    """Return a KMK key object that sends `token` over SPI on press."""
    return KC.make_key(
        names=(f"SPI_{token}",),
        on_press=lambda key, keyboard, *args: _queue_key(token),
    )

# Pre-build all the keys we need
_NLCK  = make_spi_key("NLCK")
_PSLS  = make_spi_key("PSLS")
_PAST  = make_spi_key("PAST")
_PMNS  = make_spi_key("PMNS")
_P7    = make_spi_key("P7")
_P8    = make_spi_key("P8")
_P9    = make_spi_key("P9")
_PPLS  = make_spi_key("PPLS")
_P4    = make_spi_key("P4")
_P5    = make_spi_key("P5")
_P6    = make_spi_key("P6")
_P1    = make_spi_key("P1")
_P2    = make_spi_key("P2")
_P3    = make_spi_key("P3")
_PENT  = make_spi_key("PENT")
_P0    = make_spi_key("P0")
_PDOT  = make_spi_key("PDOT")

# Custom row macros (Layer 0 last key, and all of Layer 1)
_TG1   = KC.TG(1)
_MUTE  = make_spi_key("MUTE")
_VOLD  = make_spi_key("VOLD")
_VOLU  = make_spi_key("VOLU")
_MPLY  = make_spi_key("MPLY")
_MPRV  = make_spi_key("MPRV")
_MNXT  = make_spi_key("MNXT")
_BRID  = make_spi_key("BRID")
_BRIU  = make_spi_key("BRIU")
_PSCR  = make_spi_key("PSCR")
_COPY  = make_spi_key("CTRL+C")
_CUT   = make_spi_key("CTRL+X")
_PASTE = make_spi_key("CTRL+V")
_UNDO  = make_spi_key("CTRL+Z")

XXXXXXX = KC.NO
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

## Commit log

2025-10-20 added LEDs, may remove
    [Modulus.kicad_sch]
2025-10-20 added a USB hub but don't really understand shit rn
    [Modulus.kicad_sch]
2025-10-20 added my own OLED screen, XLR ports, and a caps lock LEd
    [Modulus.kicad_sch]
2025-10-20 Finished the schematic design for this! creating modular boardas another project
    [Modulus.kicad_sch]
2025-10-27 ts so difficult :sob: - anyways completed wiring first row, and the MCUs
    [LTST-C193TGKT-5A.step, Modulus.kicad_pcb, Modulus.kicad_sch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]
2025-10-31 wired everything, but didn't run DRC-
    [Modulus.kicad_pcb, Modulus.kicad_sch]
2026-01-27 rewired some stuff, added some new stuff
    [Modulus.kicad_pcb, Modulus.kicad_sch]
2026-03-13 rerouted AGAIn
    [Modulus.kicad_pcb]
2026-03-14 finished the case and PCB designls doing BOM now
    [Modulus case (print ready).3mf, Modulus.kicad_pcb, Modulus.step]
2026-03-15 redesigning whole board so everything is at the back except the XLR stuff :pf:
    [BOM.csv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]
2026-03-15 Moved everything to the back
    [Modulus-B_Cu.gbr, Modulus-B_Mask.gbr, Modulus-B_Paste.gbr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]
2026-03-16 did clean up
    [BOM.csv, LTST-C193TGKT-5A.step, Modulus case (print ready).3mf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]
2026-03-16 more clean up
    [BOM.csv, LTST-C193TGKT-5A.step, Modulus case (print ready).3mf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]
2026-03-16 ready to ship!
    [Case.step, Full design.step, Modulus case (print ready).3mf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]
2026-03-17 added numpad+macropad
    [Modulus.kicad_sch]
2026-03-18 removed lock file
    [Modulus.kicad_pcb, Modulus.kicad_sch]
2026-03-18 added firmware, and new models
    [1.00u.step, 1.25u.step, 1.50u.step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]
2026-03-18 final commit for submission
    [Full BOM.csv, Full BOM.ods, Keyboard BOM.csv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]
2026-03-28 Updated BOM
    [Full BOM.csv, Full BOM.xlsx, Keyboard BOM.xls]
